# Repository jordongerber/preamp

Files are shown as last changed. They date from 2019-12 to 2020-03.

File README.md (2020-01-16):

# Preamp

## Goals

 * Learn Kicad
 * Become familiar with microcontroller programming
  * SPI
  * Shift registers
  * Mux/Demux
  * Controller interrupts
 * Make a bomb preamp
  * See the block diagram in [/preamp-layout/](https://github.com/SlurpyTurts/preamp/tree/master/preamp-layout) for details of the overall design.

## Implementation
* I am planning to use an ESP32 controller as the MCU
* This preamp will implement relay-controlled input and output switching
  * Inputs
    * Some number of single-ended RCA pairs
 	  * 1-2 pairs balanced pairs
    * relays controlled via demux from MCU. Input control via
      * Front panel rotary encoder
      * Front panel capacitive touch sensors
      * IR remote control
      * Because it's an ESP32, I gotta play with network control
 		* Selection remembered when the device is power-cycled
 	* Outputs
 		* 1x single-ended RCA pair
 		* 1x balanced XLR pair
 		* Headphone Amp
 			* Op-amp driven amp will have single-ended output.
 			* Preamp main outputs will be muted when the headphone amp has a device inserted
 			* When headphones are inserted the previous headphone level will be retained
 			* When headphones are unplugged the main output volume will be retained from before insertion
 		* Upon bootup the headphone volume will come in low (previous state not remembered) but not off, TBD
 * Volume control will be implemented via an MDAC controller
 * Selectable gain setting: 0dB or +12dB
 * Power Supply
 	* Separate linear power supplies for analog and digital sections
 		* 5V
 		* +-15V
 * Headphone Amp
 	* Single-ended Op-amp design
 * Tone Controls
 	* Meh. At the moment I don't really care about tone controls on this unit. If I do add them I'd like to have:
 		* Low/high pass loudness controls w/ controllable corner frequency
 		* Parametric upper-midrange control, 2kHz - 5kHz, variable Q, variable gain (-6dB to 0dB)
 		* Parametric lower-midrange control, 200Hz - 500kHz, variable Q, variable gain (-6dB to +2dB)  

## Instructions

* The files in [/preamp-code](https://github.com/SlurpyTurts/preamp/tree/master/preamp-code) can be run in the Arduino IDE. Currently it is configured for an ESP32.
* The schematic & pcb files in [/preamp-layout/preamp-kicad](https://github.com/SlurpyTurts/preamp/tree/master/preamp-layout/preamp-kicad) can be viewed using KiCad. Open the file ```preamp.pro```
* An overview of the schematic layout of this preamp is located at [preamp/preamp-layout/preamp-kicad/preamp.pdf](https://github.com/SlurpyTurts/preamp/blob/master/preamp-layout/preamp-kicad/preamp.pdf)

## References

### Preamp design
 * https://github.com/FutureSharks/preamp-two
 * https://www.muffsy.com/muffsy-relay-input-selector-4.html
 * https://sound-au.com/articles/balanced-io.htm
 * http://www.interfacebus.com/tone-control-3-band-tlo82-opamp-design.html
 * http://www.thatcorp.com/2181-series_Trimmable_Blackmer_IC_Voltage-Controlled_Amplifiers.shtml

### Power Supply design
 * https://www.eleccircuit.com/dual-adjustable-power-supply-circuit-diagram/

### SPI
 * SPI - http://www.circuitbasics.com/basics-of-the-spi-communication-protocol/
 * shift registers for mux - https://www.brainy-bits.com/get-more-inputs-on-your-arduino-by-using-a-shift-register/
 * https://github.com/espressif/arduino-esp32/blob/master/libraries/SPI/examples/SPI_Multiple_Buses/SPI_Multiple_Buses.ino
 * https://github.com/espressif/arduino-esp32/issues/1942
 * https://github.com/MajenkoLibraries/MCP23S17

### Arduino
  * encoder interrupts - http://bristolwatch.com/arduino/arduino2.htm
  * encoder interrupts - https://www.arduino.cc/reference/en/language/functions/external-interrupts/attachinterrupt/
  * flash memory - https://randomnerdtutorials.com/esp32-flash-memory/

### Other
 * Neopixel - https://www.adafruit.com/product/3094

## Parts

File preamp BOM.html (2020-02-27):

TOTAL BOM COST | 295.59
COMPONENT | SCHEMATIC ENTRY | PARTS SOURCING | FOOTPRINT ASSIGNMENT | MECHANICAL / PCB LAYOUT | CODE
CHASSIS | N/A | TODO | N/A | TODO | N/A
CABLES | N/A | TODO | N/A | TODO | N/A
AC PCA | INITIAL | INITIAL | PRELIMINARY | TODO | N/A
5V PWR PCA | INITIAL | INITIAL | PRELIMINARY | TODO | N/A
15V PWR PCA | INITIAL | INITIAL | PRELIMINARY | TODO | N/A
IO PCA | INITIAL | INITIAL | PRELIMINARY | TODO | N/A
IO SELECT PCA | INITIAL | INITIAL | PRELIMINARY | TODO | PRELIMINARY
BALANCED IO PCA | INITIAL | INITIAL | PRELIMINARY | TODO | TODO
GAIN STAGE PCA | INITIAL | PRELIMINARY | PRELIMINARY | TODO | TODO
MCU PCA | PRELIMINARY | PRELIMINARY | PRELIMINARY | TODO | TODO
FRONT PANEL SELECT PCA | INITIAL | PRELIMINARY | PRELIMINARY | TODO | TODO
HEADPHONE CROSSFEED PCA | INITIAL | TODO | TODO | TODO | TODO
HEADPHONE AMP PCA | PRELIMINARY | TODO | TODO | TODO | N/A
FINAL ASSEMBLY HARDWARE | N/A | TODO | N/A | TODO | N/A
KNOB | N/A | PRELIMINARY | N/A | TODO | N/A
PWR SWITCH | INITIAL | TODO | N/A | TODO | N/A
REMOTE | N/A | TODO | N/A | N/A | TODO
PROCESS STEPS
TODO | hasn’t been started yet
PRELIMINARY | In process of being done, not to first working draft status yet
INITIAL | draft, might be correct?
AWAITING REVIEW | inspect for completeness, correctness
CONFIRMED | has been reviewed, seems like it should work with other components.
PROTOTYPE | built, needs to be inspected to show it is working properly
TROUBLESHOOT | fix any issues found in proto
APPROVED | good to go
DONE | done
DESCRIPTION | QTY | UNIT PRICE | LINE PRICE | REF DES | NOTE | SUPPLIER | SUPPLIER PN | LINK
CHASSIS | 1 | - | - | N/A
CABLES | 1 | - | - | N/A
AC PCA | 1 | 9.12 | 9.12 | N/A
5V PWR PCA | 1 | 28.04 | 28.04 | N/A
15V PWR PCA | 1 | 47.12 | 47.12 | N/A
MAIN IO PCA | 1 | 83.86 | 83.86 | N/A
BALANCED IO PCA | 1 | 10.56 | 10.56 | N/A
IO SELECT PCA | 1 | 42.44 | 42.44 | N/A
MCU PCA | 1 | 6.53 | 6.53 | N/A
FRONT PANEL SELECT PCA | 1 | 10.36 | 10.36 | N/A
ENCODER | 2 | 1.50 | 3.00 | N/A |  | AMAZON |  | https://www.amazon.com/WGCD-KY-040-Degree-Encoder-Arduino/dp/B07B68H6R8
GAIN STAGE PCA | 1 | 29.85 | 29.85 | SW1, SW2
HEADPHONE CROSSFEED PCA | 1 | - | -
HEADPHONE AMP PCA | 1 | 0.62 | 0.62
FINAL ASSEMBLY HARDWARE | 1 |  | -
ENCODER KNOB | 2 |  | -
PWR SWITCH | 1 | 17.29 | 17.29 | SW3 |  | DIGIKEY | 1948-2261-ND | https://www.digikey.com/product-detail/en/eao/82-5151.2123/1948-2261-ND/8736349
IEC CONN | 1 | 0.88 | 0.88 |  |  | DIGIKEY | Q336-ND | https://www.digikey.com/product-detail/en/qualtek/703W-00-08/Q336-ND/1164207
REMOTE | 1 |  | - | N/A
CAPACITIVE TOUCH SWITCH MOMENTARY | 8 | 0.74 | 5.92 |  |  | AMAZON | 3-01-0019 | https://www.amazon.com/gp/product/B00HFQEFWQ/ref=ppx_yo_dt_b_asin_title_o02_s04?
DESCRIPTION | QTY | UNIT PRICE | LINE PRICE | REF DES | NOTE | SUPPLIER | SUPPLIER PN | LINK
 |  |  | -
DESCRIPTION | QTY | UNIT PRICE | LINE PRICE | REF DES | NOTE | SUPPLIER | SUPPLIER PN | LINK
 |  |  | -
DESCRIPTION | QTY | UNIT PRICE | LINE PRICE | REF DES | NOTE | SUPPLIER | SUPPLIER PN | LINK
AC PCB | 1 |  | - | N/A
CAP CER 0.1UF 1KV X7R 1812 | 1 | 0.94 | 0.94 | C1 | power switch bypass capacitor | DIGIKEY | 399-9854-1-ND | https://www.digikey.com/product-detail/en/kemet/C1812C104KDRAC7800/399-9854-1-ND/3726199
RES SMD 4.7M OHM 1% 1/4W 1206 | 1 | 0.10 | 0.10 | R1 | bleedoff resistor | DIGIKEY | 311-4.70MFRCT-ND | https://www.digikey.com/product-detail/en/yageo/RC1206FR-074M7L/311-4.70MFRCT-ND/731835
FUSE HLDR CARTRIDGE 250V 5A PCB | 1 | 0.62 | 0.62 | F1 |  | DIGIKEY | 36-4527-ND | https://www.digikey.com/product-detail/en/keystone-electronics/4527/36-4527-ND/8397
FUSE GLASS 500MA 220VAC 5X20MM | 1 | 2.38 | 2.38 | N/A | Installed in F1 | DIGIKEY | 486-1863-ND | https://www.digikey.com/products/en/circuit-protection/fuses/139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
TERM BLK 3P SIDE ENT 5.08MM PCB | 3 | 1.65 | 4.95 | J2 – J4 | Connect to AC from EIC, supply to DC supplies in preamp (120V) | DIGIKEY | 277-1248-ND | https://www.digikey.com/product-detail/en/phoenix-contact/1729131/277-1248-ND/260616
CONN HEADER VERT 2POS 2.5MM | 1 | 0.13 | 0.13 | J1 | Connect power switch to pcb | DIGIKEY | 455-1611-ND | https://www.digikey.com/product-detail/en/jst-sales-america-inc/B2B-EH-A-LF-SN/455-1611-ND/926520
DESCRIPTION | QTY | UNIT PRICE | LINE PRICE | REF DES | NOTE | SUPPLIER | SUPPLIER PN | LINK
+5V PCB | 1 |  | - | N/A
XFRMR LAMINATED 6VA THRU HOLE | 1 | 11.62 | 11.62 | T2 |  | DIGIKEY | HM4309-ND | https://www.digikey.com/product-detail/en/hammond-manufacturing/164F12/HM4309-ND/454308
BRIDGE RECT 1P 200V 1.5A 4DIP | 1 | 0.50 | 0.50 | D8 |  | DIGIKEY | DF02M-ND | https://www.digikey.com/product-detail/en/on-semiconductor/DF02M/DF02M-ND/976938
FUSE HLDR CARTRIDGE 250V 5A PCB | 1 | 0.62 | 0.62 | F3 |  | DIGIKEY | 36-4527-ND | https://www.digikey.com/product-detail/en/keystone-electronics/4527/36-4527-ND/8397
FUSE GLASS 500MA 220VAC 5X20MM | 1 | 2.38 | 2.38 | N/A | Installed in F3 | DIGIKEY | 486-1863-ND | https://www.digikey.com/products/en/circuit-protection/fuses/139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
LED RED CLEAR 1206 SMD | 1 | 0.27 | 0.27 | D9 | Power indicator LED | DIGIKEY | 160-1167-1-ND | https://www.digikey.com/product-detail/en/lite-on-inc/LTST-C150CKT/160-1167-1-ND/269239
RES SMD 430 OHM 1% 1/4W 1206 | 1 | 0.07 | 0.07 | R8 | Current set resistor for power indicator LED | DIGIKEY | 311-430FRCT-ND | https://www.digikey.com/product-detail/en/yageo/RC1206FR-07430RL/311-430FRCT-ND/731861
TERM BLK 3P SIDE ENT 5.08MM PCB | 1 | 1.65 | 1.65 | J9 | Conn to AC board. Ties to 15V supply gnd | DIGIKEY | 277-1248-ND | https://www.digikey.com/product-detail/en/phoenix-contact/1729131/277-1248-ND/260616
CONN HEADER VERT 2POS 2.5MM | 3 | 0.131 | 0.39 | J10 – J12 | 5V OUTPUT | DIGIKEY | 455-1611-ND | https://www.digikey.com/product-detail/en/jst-sales-america-inc/B2B-EH-A-LF-SN/455-1611-ND/926520
IC REG LINEAR 5V 1A TO220-3 | 1 | 1.54 | 1.54 | U1 |  | DIGIKEY | 296-47192-ND | https://www.digikey.com/product-detail/en/texas-instruments/LM7805CT-NOPB/296-47192-ND/3901929
RES 10 OHM 1W 1% AXIAL | 1 | 0.37 | 0.37 | R9 |  | DIGIKEY | RSF1FT10R0CT-ND | https://www.digikey.com/product-detail/en/stackpole-electronics-inc/RSF1FT10R0/RSF1FT10R0CT-ND/6594481
CAP ALUM 2200UF 20% 35V RADIAL | 2 | 3.04 | 6.08 | C12, C13 |  | DIGIKEY | 493-4615-ND | https://www.digikey.com/products/en/capacitors/aluminum-electrolytic-capacitors/58?k=capacitor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
CAP CER 0.1UF 50V X7R 1206 | 2 | 0.26 | 0.52 | C14, C15 |  | DIGIKEY | 311-1435-1-ND | https://www.digikey.com/product-detail/en/yageo/CC1206JRX7R9BB104/311-1435-1-ND/2833741
CAP ALUM 100UF 20% 35V RADIAL | 1 | 0.51 | 0.51 | C16 |  | DIGIKEY | 493-4662-1-ND | https://www.digikey.com/product-detail/en/nichicon/UKA1V101MED1TD/493-4662-1-ND/2787089
RES SMD 240 OHM 1% 1/4W 1206 | 1 | 0.10 | 0.10 | R10 |  | DIGIKEY | 311-240FRCT-ND | https://www.digikey.com/products/en/resistors/chip-resistor-surface-mount/52?k=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
TRIMMER 5K OHM 0.5W PC PIN TOP | 1 | 1.02 | 1.02 | RV3 | Output voltage adjustment | DIGIKEY | 3362P-502LF-ND | https://www.digikey.com/product-detail/en/bourns-inc/3362P-1-502LF/3362P-502LF-ND/1088421
DIODE GEN PURP 50V 1A SOD123FL | 2 | 0.20 | 0.40 | D10, D11 |  | DIGIKEY | SM4001PL-TPMSCT-ND | https://www.digikey.com/product-detail/en/micro-commercial-co/SM4001PL-TP/SM4001PL-TPMSCT-ND/1793403
DESCRIPTION | QTY | UNIT PRICE | LINE PRICE | REF DES | NOTE | SUPPLIER | SUPPLIER PN | LINK
+/-15V PCB | 1 |  | - | N/A
XFRMR LAMINATED 36VA THRU HOLE | 1 | 19.06 | 19.06 | T1 |  | DIGIKEY | HM4343-ND | https://www.digikey.com/product-detail/en/hammond-manufacturing/164J28/HM4343-ND/454433
BRIDGE RECT 1P 200V 1.5A 4DIP | 1 | 0.50 | 0.50 | D1 |  | DIGIKEY | DF02M-ND | https://www.digikey.com/product-detail/en/on-semiconductor/DF02M/DF02M-ND/976938
FUSE HLDR CARTRIDGE 250V 5A PCB | 1 | 0.62 | 0.62 | F2 |  | DIGIKEY | 36-4527-ND | https://www.digikey.com/product-detail/en/keystone-electronics/4527/36-4527-ND/8397
FUSE GLASS 500MA 220VAC 5X20MM | 1 | 2.38 | 2.38 | N/A | Installed in F2 | DIGIKEY | 486-1863-ND | https://www.digikey.com/products/en/circuit-protection/fuses/139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
LED GREEN CLEAR 1206 SMD | 2 | 0.24 | 0.48 | D2, D3 | Power indicator LEDs | DIGIKEY | 160-1169-1-ND | https://www.digikey.com/product-detail/en/lite-on-inc/LTST-C150GKT/160-1169-1-ND/269241
RES SMD 430 OHM 1% 1/4W 1206 | 2 | 0.07 | 0.14 | R2, R3 | Current set resistor for power indicator LEDs | DIGIKEY | 311-430FRCT-ND | https://www.digikey.com/product-detail/en/yageo/RC1206FR-07430RL/311-430FRCT-ND/731861
CONN HEADER VERT 3POS 2.5MM | 3 | 0.48 | 1.44 | J6 – J8 | +-15V OUTPUT | DIGIKEY | 455-1612-ND | https://www.digikey.com/product-detail/en/jst-sales-america-inc/B3B-EH-A-LF-SN/455-1612-ND/926521
IC REG LINEAR 5V 1A TO220-3 | 1 | 1.54 | 1.54 | U1 |  | DIGIKEY | 296-47192-ND | https://www.digikey.com/product-detail/en/texas-instruments/LM7805CT-NOPB/296-47192-ND/3901929
IC REG LINEAR -5V 1.5A TO220-3 | 1 | 1.63 | 1.63 | U2 |  | DIGIKEY | LM7905CTNS/NOPB-ND | https://www.digikey.com/product-detail/en/texas-instruments/LM7905CT-NOPB/LM7905CTNS-NOPB-ND/6349
RES 10 OHM 1W 1% AXIAL | 2 | 0.37 | 0.74 | R4, R5 |  | DIGIKEY | RSF1FT10R0CT-ND | https://www.digikey.com/product-detail/en/stackpole-electronics-inc/RSF1FT10R0/RSF1FT10R0CT-ND/6594481
CAP ALUM 2200UF 20% 35V RADIAL | 4 | 3.04 | 12.16 | C2 – C5 |  | DIGIKEY | 493-4615-ND | https://www.digikey.com/products/en/capacitors/aluminum-electrolytic-capacitors/58?k=capacitor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
DIODE GEN PURP 50V 1A SOD123FL | 4 | 0.20 | 0.80 | D4 – D7 |  | DIGIKEY | SM4001PL-TPMSCT-ND | https://www.digikey.com/product-detail/en/micro-commercial-co/SM4001PL-TP/SM4001PL-TPMSCT-ND/1793403
CAP ALUM 100UF 20% 35V RADIAL | 2 | 0.51 | 1.02 | C10, C11 |  | DIGIKEY | 493-4662-1-ND | https://www.digikey.com/product-detail/en/nichicon/UKA1V101MED1TD/493-4662-1-ND/2787089
CAP CER 0.1UF 100V X7R 0805 | 4 | 0.18 | 0.72 | C6 – C8 |  | DIGIKEY | 311-1435-1-ND | https://www.digikey.com/product-detail/en/yageo/CC1206JRX7R9BB104/311-1435-1-ND/2833741
RES SMD 240 OHM 1% 1/4W 1206 | 2 | 0.10 | 0.20 | R6, R7 |  | DIGIKEY | 311-240FRCT-ND | https://www.digikey.com/products/en/resistors/chip-resistor-surface-mount/52?k=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
TRIMMER 5K OHM 0.5W PC PIN TOP | 2 | 1.02 | 2.04 | RV1, RV2 | Output voltage adjustment | DIGIKEY | 3362P-502LF-ND | https://www.digikey.com/product-detail/en/bourns-inc/3362P-1-502LF/3362P-502LF-ND/1088421
TERM BLK 3P SIDE ENT 5.08MM PCB | 1 | 1.65 | 1.65 | J5 | Conn to AC board. Ties to 5V supply gnd | DIGIKEY | 277-1248-ND | https://www.digikey.com/product-detail/en/phoenix-contact/1729131/277-1248-ND/260616
DESCRIPTION | QTY | UNIT PRICE | LINE PRICE | REF DES | NOTE | SUPPLIER | SUPPLIER PN | LINK
MAIN IO PCB | 1 |  | - | N/A
RCA JACK PC MOUNT WHITE | 7 | 5.99 | 41.93 | J37.1 – J41.1, J49.1, J50.1 | Most likely a knockoff, I don’t care. | GOOD COMPONENT | CMC 805-2.5F-G | https://www.goodcomponent.com/products/connectors-switches/rca-connector/cmc-805-25f-g-gold-plated-brass-female-rca-jack-connector-whitered-cmc-805-25f-g-855.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
RCA JACK PC MOUNT RED | 7 | 5.99 | 41.93 | J37.2 – J41.2, J49.2, J50.2 | Most likely a knockoff, I don’t care. | GOOD COMPONENT | CMC 805-2.5F-G | https://www.goodcomponent.com/products/connectors-switches/rca-connector/cmc-805-25f-g-gold-plated-brass-female-rca-jack-connector-whitered-cmc-805-25f-g-855.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
DESCRIPTION | QTY | UNIT PRICE | LINE PRICE | REF DES | NOTE | SUPPLIER | SUPPLIER PN | LINK
BALANCED IO PCB | 1 |  | - | N/A
XLR FEMALE | 2 | 0.92 | 1.84 |  |  | MOUSER | 568-NC3FAAV-1 | https://www.mouser.com/ProductDetail/Neutrik/NC3FAAV1
XLR MALE | 2 | 0.77 | 1.54 |  |  | MOUSER | 568-NC3MAAV-1 | https://www.mouser.com/ProductDetail/Neutrik/NC3MAAV-1?qs=3hqMSz60ubQNQZ6GY809OQ%3D%3D
LED GREEN CLEAR 1206 SMD | 2 | 0.24 | 0.48 | D14, D15 | Power indicator LEDs | DIGIKEY | 160-1169-1-ND | https://www.digikey.com/product-detail/en/lite-on-inc/LTST-C150GKT/160-1169-1-ND/269241
RES SMD 430 OHM 1% 1/4W 1206 | 2 | 0.07 | 0.14 | R19, R24 | Current set resistor for power indicator LEDs | DIGIKEY | 311-430FRCT-ND | https://www.digikey.com/product-detail/en/yageo/RC1206FR-07430RL/311-430FRCT-ND/731861
IC OPAMP JFET 2 CIRCUIT 8DIP | 3 | 0.607 | 1.82 | U6 – U8 | Any dual op amp that fits TL072 Pinout | DIGIKEY | 296-14997-5-ND | https://www.digikey.com/product-detail/en/texas-instruments/TL072IP/296-14997-5-ND/563039
CONN HEADER VERT 3POS 2.5MM | 2 | 0.48 | 0.96 | J31, J32 | +/-15VDC | DIGIKEY | 455-1612-ND | https://www.digikey.com/product-detail/en/jst-sales-america-inc/B3B-EH-A-LF-SN/455-1612-ND/926521
CONN HEADER VERT 3POS 2.54MM | 1 | 0.14 | 0.14 | J34 |  | DIGIKEY | 952-2264-ND | https://www.digikey.com/product-detail/en/harwin-inc/M20-9990346/952-2264-ND/3728228
CONN RCPT 3POS 0.1 TIN PCB | 1 | 0.64 | 0.64 | J33 |  | DIGIKEY | 952-1784-ND | https://www.digikey.com/product-detail/en/harwin-inc/M20-7820346/952-1784-ND/3727753
RES SMD 1K OHM 1% 1/4W 1206 | 4 | 0.1 | 0.40 | R11 – R14 |  | DIGIKEY | 311-1.00KFRCT-ND | https://www.digikey.com/product-detail/en/yageo/RC1206FR-071KL/311-1.00KFRCT-ND/731334
RES SMD 9.09K OHM 1% 1/4W 1206 | 4 | 0.1 | 0.40 | R15 – R18 |  | DIGIKEY | 311-9.09KFRCT-ND | https://www.digikey.com/products/en/resistors/chip-resistor-surface-mount/52?k=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
RES SMD 10K OHM 1% 1/4W 1206 | 16 | 0.07 | 1.12 | R20 – R23, R27 – R38 |  | DIGIKEY | 311-10.0KFRCT-ND | https://www.digikey.com/product-detail/en/yageo/RC1206FR-0710KL/311-10.0KFRCT-ND/731430
RES SMD 100 OHM 1% 1/4W 1206 | 6 | 0.1 | 0.60 | R25, R26, R39 – R42 |  | DIGIKEY | 311-100FRCT-ND | https://www.digikey.com/product-detail/en/yageo/RC1206FR-07100RL/311-100FRCT-ND/731438
CAP CER 3300PF 100V X7R 0805 | 4 | 0.12 | 0.48 | C17 – C20 |  | DIGIKEY | 311-1471-1-ND | https://www.digikey.com/product-detail/en/yageo/CC0805KRX7R0BB332/311-1471-1-ND/2833777
DESCRIPTION | QTY | UNIT PRICE | LINE PRICE | REF DES | NOTE | SUPPLIER | SUPPLIER PN | LINK
IO SELECT PCB | 1 |  | - | N/A
IC I/O EXPANDER SPI 16B 28SDIP | 1 | 1.26 | 1.26 | U9 |  | DIGIKEY | MCP23S17-E/SP-ND | https://www.digikey.com/product-detail/en/microchip-technology/MCP23S17-E-SP/MCP23S17-E-SP-ND/894276
IC PWR RELAY 7NPN 1:1 16SO | 2 | 0.59 | 1.18 | U10, U11 |  | DIGIKEY | ULN2003ADR2GOSCT-ND | https://www.digikey.com/product-detail/en/on-semiconductor/ULN2003ADR2G/ULN2003ADR2GOSCT-ND/2623488
RELAY TELECOM DPDT 1A 5VDC | 7 | 4.69 | 32.83 | K1 – K7 |  | DIGIKEY | Z2144-ND | https://www.digikey.com/product-detail/en/omron-electronics-inc-emc-div/G6JU-2P-Y-DC5/Z2144-ND/699971
RES SMD 430 OHM 1% 1/4W 1206 | 1 | 0.07 | 0.07 | R43 | Current set resistor for power indicator LED | DIGIKEY | 311-430FRCT-ND | https://www.digikey.com/product-detail/en/yageo/RC1206FR-07430RL/311-430FRCT-ND/731861
LED RED CLEAR 1206 SMD | 1 | 0.27 | 0.27 | D16 | Power indicator LED | DIGIKEY | 160-1167-1-ND | https://www.digikey.com/product-detail/en/lite-on-inc/LTST-C150CKT/160-1167-1-ND/269239
CONN HEADER VERT 2POS 2.5MM | 2 | 0.14 | 0.28 | J61, J62 |  | DIGIKEY | 455-1611-ND | https://www.digikey.com/product-detail/en/jst-sales-america-inc/B2B-EH-A-LF-SN/455-1611-ND/926520
CONN HEADER VERT 3POS 2.54MM | 6 | 0.14 | 0.82 | J52 – J56, J59 |  | DIGIKEY | 952-2264-ND | https://www.digikey.com/product-detail/en/harwin-inc/M20-9990346/952-2264-ND/3728228
CONN RCPT 3POS 0.1 TIN PCB | 4 | 0.64 | 2.55 | J51, J60, J63, J64 |  | DIGIKEY | 952-1784-ND | https://www.digikey.com/product-detail/en/harwin-inc/M20-7820346/952-1784-ND/3727753
CONN RCPT 8POS 0.1 GOLD PCB | 2 | 1.1 | 2.20 | J57, J58 |  | DIGIKEY | 952-1823-ND | https://www.digikey.com/products/en/connectors-interconnects/rectangular-connectors-headers-receptacles-female-sockets/315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
RES SMD 51 OHM 1% 1/4W 1206 | 14 | 0.07 | 0.98 | R44 – R57 |  | DIGIKEY | 311-51.0FRCT-ND | https://www.digikey.com/product-detail/en/yageo/RC1206FR-0751RL/311-51.0FRCT-ND/731920
DESCRIPTION | QTY | UNIT PRICE | LINE PRICE | REF DES | NOTE | SUPPLIER | SUPPLIER PN | LINK
GAIN STAGE PCB | 1 |  | - | N/A
RES SMD 430 OHM 1% 1/4W 1206 | 2 | 0.07 | 0.14 | R82, R83, R86 | Current set resistor for power indicator LEDs | DIGIKEY | 311-430FRCT-ND | https://www.digikey.com/product-detail/en/yageo/RC1206FR-07430RL/311-430FRCT-ND/731861
LED GREEN CLEAR 1206 SMD | 2 | 0.24 | 0.48 | D17, D18 | Power indicator LEDs | DIGIKEY | 160-1169-1-ND | https://www.digikey.com/product-detail/en/lite-on-inc/LTST-C150GKT/160-1169-1-ND/269241
LED RED CLEAR 1206 SMD | 1 | 0.27 | 0.27 | D21 | Power indicator LED | DIGIKEY | 160-1167-1-ND | https://www.digikey.com/product-detail/en/lite-on-inc/LTST-C150CKT/160-1167-1-ND/269239
IC DAC 8BIT V-OUT 14SOIC | 2 | 1.29 | 2.58 | U12, U13 | DAC to set gain | DIGIKEY | MCP4902-E/SL-ND | https://www.digikey.com/product-detail/en/microchip-technology/MCP4902-E-SL/MCP4902-E-SL-ND/2332822
IC OPAMP JFET 2 CIRCUIT 8DIP | 4 | 0.607 | 2.43 | U14, U15, U18, U21 | Any dual op amp that fits TL072 Pinout | DIGIKEY | 296-14997-5-ND | https://www.digikey.com/product-detail/en/texas-instruments/TL072IP/296-14997-5-ND/563039
Audio Amplifiers Trimmable VCA .02% THD | 4 | 5.05 | 20.20 | U16, U17, U19, U20 | Sets gain of preamp, ctrl voltage supplied from MCP4902 | MOUSER | 887-2181CS08-U | https://www.mouser.com/ProductDetail/THAT/2181CS08-U
RES SMD 330 OHM 1% 1/4W 1206 | 1 | 0.07 | 0.07 | R86 | Current set resistor for power indicator LEDs | DIGIKEY | 311-330FRCT-ND | https://www.digikey.com/products/en/resistors/chip-resistor-surface-mount/52?k=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
RES SMD 2K OHM 1% 1/4W 1206 | 4 | 0.1 | 0.40 | R70 – R73 |  | DIGIKEY | 311-2.00KFRCT-ND | https://www.digikey.com/product-detail/en/yageo/RC1206FR-072KL/311-2.00KFRCT-ND/731559
RES SMD 178K OHM 1% 1/4W 1206 | 4 | $0.10 | 0.40 | R62, R64, R66, R68 |  | DIGIKEY | 311-178KFRCT-ND | https://www.digikey.com/product-detail/en/yageo/RC1206FR-07178KL/311-178KFRCT-ND/731537
RES SMD 6.49K OHM 1% 1/4W 1206 | 4 | $0.10 | 0.40 | R63, R65, R67, R69 |  | DIGIKEY | 311-6.49KFRCT-ND | https://www.digikey.com/product-detail/en/yageo/RC1206FR-076K49L/311-6.49KFRCT-ND/731969
RES SMD 6.34K OHM 1% 1/4W 1206 | 4 | $0.10 | 0.40 | R58 – R61 |  | DIGIKEY | 311-6.34KFRCT-ND | https://www.digikey.com/product-detail/en/yageo/RC1206FR-076K34L/311-6.34KFRCT-ND/731966
CAP CER 0.1UF 100V X7R 0805 | 4 | $0.18 | 0.72 | C21 – C24 |  | DIGIKEY | 311-2083-1-ND | https://www.digikey.com/product-detail/en/yageo/CC0805KKX7R0BB104/311-2083-1-ND/5962185
RES SMD 20K OHM 1% 1/4W 1206 | 8 | $0.10 | 0.80 | R74 – R81 |  | DIGIKEY | 311-20.0KFRCT-ND | https://www.digikey.com/product-detail/en/yageo/RC1206FR-0720KL/311-20.0KFRCT-ND/731619
CAP CER 22PF 100V C0G/NPO 0805 | 4 | $0.14 | 0.56 | C31, C32, C35, C36 |  | DIGIKEY | 311-1840-1-ND | https://www.digikey.com/product-detail/en/yageo/CC0805JRNPO0BN220/311-1840-1-ND/5195742
DESCRIPTION | QTY | UNIT PRICE | LINE PRICE | REF DES | NOTE | SUPPLIER | SUPPLIER PN | LINK
MCU PCB | 1 |  | - | N/A
ESP32 MCU | 1 | 6.53 | 6.53 |  |  | AMAZON |  | https://www.amazon.com/gp/product/B07Q576VWZ/ref=ppx_yo_dt_b_asin_title_o02_s01?ie=UTF8&psc=1
DESCRIPTION | QTY | UNIT PRICE | LINE PRICE | REF DES | NOTE | SUPPLIER | SUPPLIER PN | LINK
FRONT PANEL PCB | 1 |  | - | N/A
MULTIPLE SWITCH DETECTION INTERFACE | 1 | 4.19 | 4.19 |  | condenses up to 22 input switches to SPI and flag line | DIGIKEY | MC33978AEK-ND | https://www.digikey.com/product-detail/en/nxp-usa-inc/MC33978AEK/MC33978AEK-ND/5451804
CONN HEADER VERT 3POS 2.5MM | 8 | 0.48 | 3.84 | J72 – J79 |  | DIGIKEY | 455-1612-ND | https://www.digikey.com/product-detail/en/jst-sales-america-inc/B3B-EH-A-LF-SN/455-1612-ND/926521
RES SMD 100 OHM 1% 1/4W 1206 | 8 | 0.07 | 0.56 | R87 – R94 |  | DIGIKEY | 311-100FRCT-ND | https://www.digikey.com/product-detail/en/yageo/RC1206FR-07100RL/311-100FRCT-ND/731438
CAP CER 0.1UF 100V X7R 1206 | 8 | 0.13 | 1.04 | C37 – C44 |  | DIGIKEY | 311-1488-1-ND | https://www.digikey.com/product-detail/en/yageo/CC1206KKX7R0BB104/311-1488-1-ND/2833794
LED RED CLEAR 1206 SMD | 1 | 0.27 | 0.27 | D9 | Power indicator LED | DIGIKEY | 160-1167-1-ND | https://www.digikey.com/product-detail/en/lite-on-inc/LTST-C150CKT/160-1167-1-ND/269239
RES SMD 330 OHM 1% 1/4W 1206 | 1 | 0.07 | 0.07 | R8 | Current set resistor for power indicator LEDs | DIGIKEY | 311-330FRCT-ND | https://www.digikey.com/products/en/resistors/chip-resistor-surface-mount/52?k=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
CONN HEADER VERT 2POS 2.5MM | 3 | 0.13 | 0.39 | J10 – J12 | 5V OUTPUT | DIGIKEY | 455-1611-ND | https://www.digikey.com/product-detail/en/jst-sales-america-inc/B2B-EH-A-LF-SN/455-1611-ND/926520
DESCRIPTION | QTY | UNIT PRICE | LINE PRICE | REF DES | NOTE | SUPPLIER | SUPPLIER PN | LINK
HEADPHONE CROSSFEED PCB | 1 |  | - | N/A
DESCRIPTION | QTY | UNIT PRICE | LINE PRICE | REF DES | NOTE | SUPPLIER | SUPPLIER PN | LINK
HEADPHONE AMP PCB | 1 |  | - | N/A
LED GREEN CLEAR 1206 SMD | 2 | 0.24 | 0.48 | D19, D20 | Power indicator LEDs | DIGIKEY | 160-1169-1-ND | https://www.digikey.com/product-detail/en/lite-on-inc/LTST-C150GKT/160-1169-1-ND/269241
RES SMD 430 OHM 1% 1/4W 1206 | 2 | 0.07 | 0.14 | R84, R85 | Current set resistor for power indicator LEDs | DIGIKEY | 311-430FRCT-ND | https://www.digikey.com/product-detail/en/yageo/RC1206FR-07430RL/311-430FRCT-ND/731861
DESCRIPTION | QTY | UNIT PRICE | LINE PRICE | REF DES | NOTE | SUPPLIER | SUPPLIER PN | LINK
ENCODER PCB | 1 |  | - | N/A
ROTARY ENCODER | 2 | 1.50 | 3.00 |  |  | AMAZON |  | https://www.amazon.com/WGCD-KY-040-Degree-Encoder-Arduino/dp/B07B68H6R8
https://www.aliexpress.com/item/32826735571.html?scm_id=1007.13338.146400.0&scm-url=1007.13338.146400.0
https://www.aliexpress.com/item/32800269274.html?scm_id=1007.13338.146400.0&scm-url=1007.13338.146400.0
https://www.aliexpress.com/item/32953404871.html?scm_id=1007.13338.146400.0&scm-url=1007.13338.146400.0
https://www.aliexpress.com/item/32627105289.html?scm_id=1007.13338.146400.0&scm-url=1007.13338.146400.0

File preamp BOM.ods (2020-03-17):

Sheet: OVERVIEW
TOTAL BOM COST | $316.82
COMPONENT | SCHEMATIC ENTRY | PARTS SOURCING | FOOTPRINT ASSIGNMENT | MECHANICAL / PCB LAYOUT | CODE
CHASSIS | N/A | TODO | N/A | TODO | N/A
CABLES | N/A | TODO | N/A | TODO | N/A
AC PCA | INITIAL | INITIAL | PRELIMINARY | TODO | N/A
5V PWR PCA | INITIAL | INITIAL | PRELIMINARY | TODO | N/A
15V PWR PCA | INITIAL | INITIAL | PRELIMINARY | TODO | N/A
IO PCA | INITIAL | INITIAL | PRELIMINARY | TODO | N/A
IO SELECT PCA | INITIAL | INITIAL | PRELIMINARY | TODO | PRELIMINARY
BALANCED IO PCA | INITIAL | INITIAL | PRELIMINARY | TODO | TODO
GAIN STAGE PCA | INITIAL | INITIAL | PRELIMINARY | TODO | TODO
MCU PCA | PRELIMINARY | PRELIMINARY | PRELIMINARY | TODO | TODO
FRONT PANEL SELECT PCA | INITIAL | PRELIMINARY | PRELIMINARY | TODO | TODO
HEADPHONE CROSSFEED PCA | INITIAL | TODO | TODO | TODO | TODO
HEADPHONE AMP PCA | INITIAL | TODO | TODO | TODO | N/A
FINAL ASSEMBLY HARDWARE | N/A | TODO | N/A | TODO | N/A
KNOB | N/A | PRELIMINARY | N/A | TODO | N/A
PWR SWITCH | INITIAL | TODO | N/A | TODO | N/A
REMOTE | N/A | TODO | N/A | N/A | TODO
PROCESS STEPS
TODO | hasn’t been started yet
PRELIMINARY | In process of being done, not to first working draft status yet
INITIAL | draft, might be correct?
AWAITING REVIEW | inspect for completeness, correctness
CONFIRMED | has been reviewed, seems like it should work with other components.
PROTOTYPE | built, needs to be inspected to show it is working properly
TROUBLESHOOT | fix any issues found in proto
APPROVED | good to go
DONE | done

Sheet: MAIN ASSEMBLY
DESCRIPTION | QTY | UNIT PRICE | LINE PRICE | REF DES | NOTE | SUPPLIER | SUPPLIER PN | LINK
CHASSIS | 1 | $0.00 | $0.00 | N/A
CABLES | 1 | $0.00 | $0.00 | N/A
AC PCA | 1 | $13.62 | $13.62 | N/A
5V PWR PCA | 1 | $28.04 | $28.04 | N/A
15V PWR PCA | 1 | $47.06 | $47.06 | N/A
MAIN IO PCA | 1 | $83.86 | $83.86 | N/A
BALANCED IO PCA | 1 | $12.64 | $12.64 | N/A
IO SELECT PCA | 1 | $41.49 | $41.49 | N/A
MCU PCA | 1 | $6.53 | $6.53 | N/A
FRONT PANEL SELECT PCA | 1 | $10.67 | $10.67 | N/A
ENCODER | 2 | $1.50 | $3.00 | N/A |  | AMAZON |  | https://www.amazon.com/WGCD-KY-040-Degree-Encoder-Arduino/dp/B07B68H6R8
GAIN STAGE PCA | 1 | $36.25 | $36.25 | SW1, SW2
HEADPHONE CROSSFEED PCA | 1 | $2.24 | $2.24
HEADPHONE AMP PCA | 1 | $7.33 | $7.33
FINAL ASSEMBLY HARDWARE | 1 |  | $0.00
ENCODER KNOB | 2 |  | $0.00
PWR SWITCH | 1 | $17.29 | $17.29 | SW3 |  | DIGIKEY | 1948-2261-ND | https://www.digikey.com/product-detail/en/eao/82-5151.2123/1948-2261-ND/8736349
IEC CONN | 1 | $0.88 | $0.88 |  |  | DIGIKEY | Q336-ND | https://www.digikey.com/product-detail/en/qualtek/703W-00-08/Q336-ND/1164207
REMOTE | 1 |  | $0.00 | N/A
CAPACITIVE TOUCH SWITCH MOMENTARY | 8 | $0.74 | $5.92 |  |  | AMAZON | 3-01-0019 | https://www.amazon.com/gp/product/B00HFQEFWQ/ref=ppx_yo_dt_b_asin_title_o02_s04?

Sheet: CHASSIS
DESCRIPTION | QTY | UNIT PRICE | LINE PRICE | REF DES | NOTE | SUPPLIER | SUPPLIER PN | LINK
 |  |  | $-

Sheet: CABLES
DESCRIPTION | QTY | UNIT PRICE | LINE PRICE | REF DES | NOTE | SUPPLIER | SUPPLIER PN | LINK
 |  |  | $-

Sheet: AC PCA
DESCRIPTION | QTY | UNIT PRICE | LINE PRICE | REF DES | NOTE | SUPPLIER | SUPPLIER PN | LINK
AC PCB | 1 |  | $0.00 | N/A
CAP CER 0.1UF 1KV X7R 1812 | 1 | $0.94 | $0.94 | C1 | power switch bypass capacitor | DIGIKEY | 399-9854-1-ND | https://www.digikey.com/product-detail/en/kemet/C1812C104KDRAC7800/399-9854-1-ND/3726199
RES SMD 4.7M OHM 1% 1/4W 1206 | 1 | $0.10 | $0.10 | R1 | bleedoff resistor | DIGIKEY | 311-4.70MFRCT-ND | https://www.digikey.com/product-detail/en/yageo/RC1206FR-074M7L/311-4.70MFRCT-ND/731835
FUSE HLDR CARTRIDGE 250V 5A PCB | 1 | $0.62 | $0.62 | F1 |  | DIGIKEY | 36-4527-ND | https://www.digikey.com/product-detail/en/keystone-electronics/4527/36-4527-ND/8397
FUSE GLASS 500MA 220VAC 5X20MM | 1 | $2.38 | $2.38 | N/A | Installed in F1 | DIGIKEY | 486-1863-ND | https://www.digikey.com/products/en/circuit-protection/fuses/139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
TERM BLK 3P SIDE ENT 5.08MM PCB | 3 | $1.65 | $4.95 | J2, J5, J7 | Connect to AC from EIC, supply to DC supplies in preamp (120V) | DIGIKEY | 277-1248-ND | https://www.digikey.com/product-detail/en/phoenix-contact/1729131/277-1248-ND/260616
CONN HEADER VERT 2POS 2.5MM | 1 | $0.13 | $0.13 | J3 | Connect power switch to pcb | DIGIKEY | 455-1611-ND | https://www.digikey.com/product-detail/en/jst-sales-america-inc/B2B-EH-A-LF-SN/455-1611-ND/926520
RELAY GEN PURPOSE SPST 16A 5V | 1 | $3.60 | $3.60 | K1 | +/-15V control relay | DIGIKEY | Z5412-ND | https://www.digikey.com/product-detail/en/omron-electronics-inc-emc-div/G5RLU-1A-E-DC5/Z5412-ND/4947140
CONN HDR 2POS 0.1 GOLD PCB | 1 | $0.33 | $0.33 | J6 | relay control from MCU | DIGIKEY | S7035-ND | https://www.digikey.com/product-detail/en/sullins-connector-solutions/PPPC021LFBN-RC/S7035-ND/810174
JUMPER SKT CLOSED TOP BLACK | 1 | $0.35 | $0.35 | N/A | relay bypass jumper | DIGIKEY | 952-2573-ND | https://www.digikey.com/product-detail/en/harwin-inc/M7767-05/952-2573-ND/3922868
CONN HEADER VERT 2POS 2.54MM | 1 | $0.22 | $0.22 | J4 | relay bypass | DIGIKEY | S1011E-02-ND | https://www.digikey.com/product-detail/en/sullins-connector-solutions/PBC02SAAN/S1011E-02-ND/859623

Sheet: 5V PWR PCA
DESCRIPTION | QTY | UNIT PRICE | LINE PRICE | REF DES | NOTE | SUPPLIER | SUPPLIER PN | LINK
+5V PCB | 1 |  | $0.00 | N/A
XFRMR LAMINATED 6VA THRU HOLE | 1 | $11.62 | $11.62 | T2 |  | DIGIKEY | HM4309-ND | https://www.digikey.com/product-detail/en/hammond-manufacturing/164F12/HM4309-ND/454308
BRIDGE RECT 1P 200V 1.5A 4DIP | 1 | $0.50 | $0.50 | D10 |  | DIGIKEY | DF02M-ND | https://www.digikey.com/product-detail/en/on-semiconductor/DF02M/DF02M-ND/976938
FUSE HLDR CARTRIDGE 250V 5A PCB | 1 | $0.62 | $0.62 | F3 |  | DIGIKEY | 36-4527-ND | https://www.digikey.com/product-detail/en/keystone-electronics/4527/36-4527-ND/8397
FUSE GLASS 500MA 220VAC 5X20MM | 1 | $2.38 | $2.38 | N/A | Installed in F3 | DIGIKEY | 486-1863-ND | https://www.digikey.com/products/en/circuit-protection/fuses/139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
LED RED CLEAR 1206 SMD | 1 | $0.27 | $0.27 | D8 | Power indicator LED | DIGIKEY | 160-1167-1-ND | https://www.digikey.com/product-detail/en/lite-on-inc/LTST-C150CKT/160-1167-1-ND/269239
RES SMD 330 OHM 1% 1/4W 1206 | 1 | $0.07 | $0.07 | R8 | Current set resistor for power indicator LED D8 | DIGIKEY | 311-330FRCT-ND | https://www.digikey.com/product-detail/en/yageo/RC1206FR-07330RL/311-330FRCT-ND/731769
TERM BLK 3P SIDE ENT 5.08MM PCB | 1 | $1.65 | $1.65 | J15 | Conn to AC board. Ties to 15V supply gnd | DIGIKEY | 277-1248-ND | https://www.digikey.com/product-detail/en/phoenix-contact/1729131/277-1248-ND/260616
CONN HEADER VERT 2POS 2.5MM | 3 | $0.13 | $0.39 | J12 – J14 | +5V | DIGIKEY | 455-1611-ND | https://www.digikey.com/product-detail/en/jst-sales-america-inc/B2B-EH-A-LF-SN/455-1611-ND/926520
IC REG LINEAR 5V 1A TO220-3 | 1 | $1.54 | $1.54 | U3 |  | DIGIKEY | 296-47192-ND | https://www.digikey.com/product-detail/en/texas-instruments/LM7805CT-NOPB/296-47192-ND/3901929
RES 10 OHM 1W 1% AXIAL | 1 | $0.37 | $0.37 | R9 |  | DIGIKEY | RSF1FT10R0CT-ND | https://www.digikey.com/product-detail/en/stackpole-electronics-inc/RSF1FT10R0/RSF1FT10R0CT-ND/6594481
CAP ALUM 2200UF 20% 35V RADIAL | 2 | $3.04 | $6.08 | C12, C13 |  | DIGIKEY | 493-4615-ND | https://www.digikey.com/products/en/capacitors/aluminum-electrolytic-capacitors/58?k=capacitor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
CAP CER 0.1UF 100V X7R 0805 | 2 | $0.26 | $0.52 | C14, C15 |  | DIGIKEY | 311-1435-1-ND | https://www.digikey.com/product-detail/en/yageo/CC1206JRX7R9BB104/311-1435-1-ND/2833741
CAP ALUM 100UF 20% 35V RADIAL | 1 | $0.51 | $0.51 | C16 |  | DIGIKEY | 493-4662-1-ND | https://www.digikey.com/product-detail/en/nichicon/UKA1V101MED1TD/493-4662-1-ND/2787089
RES SMD 240 OHM 1% 1/4W 1206 | 1 | $0.10 | $0.10 | R10 |  | DIGIKEY | 311-240FRCT-ND | https://www.digikey.com/products/en/resistors/chip-resistor-surface-mount/52?k=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
TRIMMER 5K OHM 0.5W PC PIN TOP | 1 | $1.02 | $1.02 | RV3 | Output voltage adjustment | DIGIKEY | 3362P-502LF-ND | https://www.digikey.com/product-detail/en/bourns-inc/3362P-1-502LF/3362P-502LF-ND/1088421
DIODE GEN PURP 50V 1A SOD123FL | 2 | $0.20 | $0.40 | D9, D11 |  | DIGIKEY | SM4001PL-TPMSCT-ND | https://www.digikey.com/product-detail/en/micro-commercial-co/SM4001PL-TP/SM4001PL-TPMSCT-ND/1793403

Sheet: 15V PWR PCA
DESCRIPTION | QTY | UNIT PRICE | LINE PRICE | REF DES | NOTE | SUPPLIER | SUPPLIER PN | LINK
+/-15V PCB | 1 |  | $0.00 | N/A
XFRMR LAMINATED 36VA THRU HOLE | 1 | $19.06 | $19.06 | T1 |  | DIGIKEY | HM4343-ND | https://www.digikey.com/product-detail/en/hammond-manufacturing/164J28/HM4343-ND/454433
BRIDGE RECT 1P 200V 1.5A 4DIP | 1 | $0.50 | $0.50 | D1 |  | DIGIKEY | DF02M-ND | https://www.digikey.com/product-detail/en/on-semiconductor/DF02M/DF02M-ND/976938
FUSE HLDR CARTRIDGE 250V 5A PCB | 1 | $0.62 | $0.62 | F2 |  | DIGIKEY | 36-4527-ND | https://www.digikey.com/product-detail/en/keystone-electronics/4527/36-4527-ND/8397
FUSE GLASS 500MA 220VAC 5X20MM | 1 | $2.38 | $2.38 | N/A | Installed in F2 | DIGIKEY | 486-1863-ND | https://www.digikey.com/products/en/circuit-protection/fuses/139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
LED GREEN CLEAR 1206 SMD | 2 | $0.24 | $0.48 | D2, D3 | Power indicator LEDs | DIGIKEY | 160-1169-1-ND | https://www.digikey.com/product-detail/en/lite-on-inc/LTST-C150GKT/160-1169-1-ND/269241
RES SMD 1.5K OHM 1% 1/4W 1206 | 2 | $0.07 | $0.14 | R2, R3 | Current set resistor for power indicator LEDs | DIGIKEY | 311-1.50KFRCT-ND | https://www.digikey.com/product-detail/en/yageo/RC1206FR-071K5L/311-1-50KFRCT-ND/731388
CONN HEADER VERT 3POS 2.5MM | 3 | $0.48 | $1.44 | J9 – J11 | +/-15V | DIGIKEY | 455-1612-ND | https://www.digikey.com/product-detail/en/jst-sales-america-inc/B3B-EH-A-LF-SN/455-1612-ND/926521
IC REG LINEAR 15V 1A TO220-3 | 1 | $1.54 | $1.54 | U1 |  | DIGIKEY | 296-44418-5-ND | https://www.digikey.com/product-detail/en/texas-instruments/LM7815CT-NOPB/296-44418-5-ND/3901976
IC REG LINEAR -15V 1.5A TO220-3 | 1 | $1.57 | $1.57 | U2 |  | DIGIKEY | LM7915CT/NOPB-ND | https://www.digikey.com/product-detail/en/texas-instruments/LM7915CT-NOPB/LM7915CT-NOPB-ND/6357
RES 10 OHM 1W 1% AXIAL | 2 | $0.37 | $0.74 | R4, R5 |  | DIGIKEY | RSF1FT10R0CT-ND | https://www.digikey.com/product-detail/en/stackpole-electronics-inc/RSF1FT10R0/RSF1FT10R0CT-ND/6594481
CAP ALUM 2200UF 20% 35V RADIAL | 4 | $3.04 | $12.16 | C2 – C5 |  | DIGIKEY | 493-4615-ND | https://www.digikey.com/products/en/capacitors/aluminum-electrolytic-capacitors/58?k=capacitor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
DIODE GEN PURP 50V 1A SOD123FL | 4 | $0.20 | $0.80 | D4 – D7 |  | DIGIKEY | SM4001PL-TPMSCT-ND | https://www.digikey.com/product-detail/en/micro-commercial-co/SM4001PL-TP/SM4001PL-TPMSCT-ND/1793403
CAP ALUM 100UF 20% 35V RADIAL | 2 | $0.51 | $1.02 | C10, C11 |  | DIGIKEY | 493-4662-1-ND | https://www.digikey.com/product-detail/en/nichicon/UKA1V101MED1TD/493-4662-1-ND/2787089
CAP CER 0.1UF 100V X7R 0805 | 4 | $0.18 | $0.72 | C6 – C9 |  | DIGIKEY | 311-1435-1-ND | https://www.digikey.com/product-detail/en/yageo/CC1206JRX7R9BB104/311-1435-1-ND/2833741
RES SMD 240 OHM 1% 1/4W 1206 | 2 | $0.10 | $0.20 | R6, R7 |  | DIGIKEY | 311-240FRCT-ND | https://www.digikey.com/products/en/resistors/chip-resistor-surface-mount/52?k=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
TRIMMER 5K OHM 0.5W PC PIN TOP | 2 | $1.02 | $2.04 | RV1, RV2 | Output voltage adjustment | DIGIKEY | 3362P-502LF-ND | https://www.digikey.com/product-detail/en/bourns-inc/3362P-1-502LF/3362P-502LF-ND/1088421
TERM BLK 3P SIDE ENT 5.08MM PCB | 1 | $1.65 | $1.65 | J8 | Conn to AC board. Ties to 5V supply gnd | DIGIKEY | 277-1248-ND | https://www.digikey.com/product-detail/en/phoenix-contact/1729131/277-1248-ND/260616

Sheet: MAIN IO PCA
DESCRIPTION | QTY | UNIT PRICE | LINE PRICE | REF DES | NOTE | SUPPLIER | SUPPLIER PN | LINK
MAIN IO PCB | 1 |  | $0.00 | N/A
RCA JACK PC MOUNT WHITE | 7 | $5.99 | $41.93 | J36.1 – J40.1, J48.1, J49.1 | Most likely a knockoff, I don’t care. | GOOD COMPONENT | CMC 805-2.5F-G | https://www.goodcomponent.com/products/connectors-switches/rca-connector/cmc-805-25f-g-gold-plated-brass-female-rca-jack-connector-whitered-cmc-805-25f-g-855.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
RCA JACK PC MOUNT RED | 7 | $5.99 | $41.93 | J36.2 – J40.2, J48.2, J49.2 | Most likely a knockoff, I don’t care. | GOOD COMPONENT | CMC 805-2.5F-G | https://www.goodcomponent.com/products/connectors-switches/rca-connector/cmc-805-25f-g-gold-plated-brass-female-rca-jack-connector-whitered-cmc-805-25f-g-855.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

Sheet: BALANCED IO PCA
DESCRIPTION | QTY | UNIT PRICE | LINE PRICE | REF DES | NOTE | SUPPLIER | SUPPLIER PN | LINK
BALANCED IO PCB | 1 |  | $0.00 | N/A
XLR FEMALE | 2 | $0.92 | $1.84 | J82, J88 |  | MOUSER | 568-NC3FAAV-1 | https://www.mouser.com/ProductDetail/Neutrik/NC3FAAV1
XLR MALE | 2 | $0.77 | $1.54 | J83, J89 |  | MOUSER | 568-NC3MAAV-1 | https://www.mouser.com/ProductDetail/Neutrik/NC3MAAV-1?qs=3hqMSz60ubQNQZ6GY809OQ%3D%3D
LED GREEN CLEAR 1206 SMD | 2 | $0.24 | $0.48 | D59, D60 | Power indicator LEDs | DIGIKEY | 160-1169-1-ND | https://www.digikey.com/product-detail/en/lite-on-inc/LTST-C150GKT/160-1169-1-ND/269241
RES SMD 1.5K OHM 1% 1/4W 1206 | 2 | $0.07 | $0.14 | R100, R105 | Current set resistor for power indicator LEDs | DIGIKEY | 311-1.50KFRCT-ND | https://www.digikey.com/product-detail/en/yageo/RC1206FR-071K5L/311-1-50KFRCT-ND/731388
IC OPAMP GP 2 CIRCUIT 8DMP | 3 | $0.76 | $2.28 | U21 – U23 | Dual op amp standard pinout | DIGIKEY | NJM2068M-ND | https://www.digikey.com/product-detail/en/njr-corporation-njrc/NJM2068M/NJM2068M-ND/805545
CONN HEADER VERT 3POS 2.5MM | 2 | $0.48 | $0.96 | J84, J85 | +/-15VDC | DIGIKEY | 455-1612-ND | https://www.digikey.com/product-detail/en/jst-sales-america-inc/B3B-EH-A-LF-SN/455-1612-ND/926521
CONN HEADER VERT 3POS 2.54MM | 1 | $0.30 | $0.30 | J87 |  | DIGIKEY | S1011E-03-ND | https://www.digikey.com/product-detail/en/sullins-connector-solutions/PBC03SAAN/S1011E-03-ND/859624
CONN HDR 3POS 0.1 GOLD PCB | 1 | $0.37 | $0.37 | J86 |  | DIGIKEY | S7036-ND | https://www.digikey.com/product-detail/en/sullins-connector-solutions/PPPC031LFBN-RC/S7036-ND/810175
RES SMD 909 OHM 1% 1/4W 1206 | 4 | $0.10 | $0.40 | R93, R94, R110, R111 |  | DIGIKEY | 311-909FRCT-ND | https://www.digikey.com/products/en?keywords=%09311-909FRCT-ND
RES SMD 9.09K OHM 1% 1/4W 1206 | 4 | $0.10 | $0.40 | R97, R98, R113, R114 |  | DIGIKEY | 311-9.09KFRCT-ND | https://www.digikey.com/products/en/resistors/chip-resistor-surface-mount/52?k=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
RES SMD 10K OHM 1% 1/4W 1206 | 16 | $0.07 | $1.12 | R90 - R92, R95, R96, R99, R103, R104, R107 – R109, R112, R115, R116, R119, R120 |  | DIGIKEY | 311-10.0KFRCT-ND | https://www.digikey.com/product-detail/en/yageo/RC1206FR-0710KL/311-10.0KFRCT-ND/731430
RES SMD 100 OHM 1% 1/4W 1206 | 6 | $0.10 | $0.60 | R101, R102, R106, R117, R118, R121 |  | DIGIKEY | 311-100FRCT-ND | https://www.digikey.com/product-detail/en/yageo/RC1206FR-07100RL/311-100FRCT-ND/731438
CAP CER 3300PF 100V X7R 0805 | 4 | $0.12 | $0.48 | C49 – C52 |  | DIGIKEY | 311-1471-1-ND | https://www.digikey.com/product-detail/en/yageo/CC0805KRX7R0BB332/311-1471-1-ND/2833777
CAP CER 0.1UF 50V X7R 0805 | 6 | $0.09 | $0.55 | C67 – C72 |  | DIGIKEY | 311-1140-1-ND | https://www.digikey.com/product-detail/en/yageo/CC0805KRX7R9BB104/311-1140-1-ND/303050
RES SMD 100K OHM 1% 1/4W 1206 | 2 | $0.10 | $0.20 | R68, R69 | output high pass filter | DIGIKEY | 311-100KFRCT-ND | https://www.digikey.com/products/en?keywords=311-100KFRCT-ND
SMD/SMT 22UF 25V 20% 0805 | 2 | $0.49 | $0.98 | C73, C74 | output high pass filter | MOUSER | 81-GRM21BR61E226ME4K | https://www.mouser.com/ProductDetail/Murata-Electronics/GRM21BR61E226ME44K

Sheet: IO SELECT PCA
DESCRIPTION | QTY | UNIT PRICE | LINE PRICE | REF DES | NOTE | SUPPLIER | SUPPLIER PN | LINK
IO SELECT PCB | 1 |  | $0.00 | N/A
IC I/O EXPANDER SPI 16B 28SOIC | 1 | $1.26 | $1.26 | U6 |  | DIGIKEY | MCP23S17-E/SO-ND | https://www.digikey.com/product-detail/en/microchip-technology/MCP23S17-E-SO/MCP23S17-E-SO-ND/894275
IC PWR RELAY 7NPN 1:1 16SO | 2 | $0.59 | $1.18 | U7, U8 |  | DIGIKEY | ULN2003ADR2GOSCT-ND | https://www.digikey.com/product-detail/en/on-semiconductor/ULN2003ADR2G/ULN2003ADR2GOSCT-ND/2623488
RELAY TELECOM DPDT 1A 5VDC | 7 | $4.69 | $32.83 | K2 – K8 |  | DIGIKEY | Z2144-ND | https://www.digikey.com/product-detail/en/omron-electronics-inc-emc-div/G6JU-2P-Y-DC5/Z2144-ND/699971
RES SMD 330 OHM 1% 1/4W 1206 | 1 | $0.07 | $0.07 | R20 | Current set resistor for power indicator LED | DIGIKEY | 311-330FRCT-ND | https://www.digikey.com/product-detail/en/yageo/RC1206FR-07330RL/311-330FRCT-ND/731769
LED RED CLEAR 1206 SMD | 1 | $0.27 | $0.27 | D13 | Power indicator LED | DIGIKEY | 160-1167-1-ND | https://www.digikey.com/product-detail/en/lite-on-inc/LTST-C150CKT/160-1167-1-ND/269239
CONN HEADER VERT 2POS 2.5MM | 2 | $0.14 | $0.28 | J60, J61 | +5V | DIGIKEY | 455-1611-ND | https://www.digikey.com/product-detail/en/jst-sales-america-inc/B2B-EH-A-LF-SN/455-1611-ND/926520
CONN HEADER VERT 3POS 2.54MM | 6 | $0.30 | $1.80 | J51 – J54, J57, J58 |  | DIGIKEY | S1011E-03-ND | https://www.digikey.com/product-detail/en/sullins-connector-solutions/PBC03SAAN/S1011E-03-ND/859624
CONN HDR 3POS 0.1 GOLD PCB | 4 | $0.37 | $1.48 | J50, J59, J62, J63 |  | DIGIKEY | S7036-ND | https://www.digikey.com/product-detail/en/sullins-connector-solutions/PPPC031LFBN-RC/S7036-ND/810175
CONN HDR 8POS 0.1 GOLD PCB | 2 | $0.67 | $1.34 | J55, J56 | RELAY CONTROL (OPTIONAL) | DIGIKEY | S7041-ND | https://www.digikey.com/product-detail/en/sullins-connector-solutions/PPPC081LFBN-RC/S7041-ND/810180
RES SMD 51 OHM 1% 1/4W 1206 | 14 | $0.07 | $0.98 | R21 – R34 |  | DIGIKEY | 311-51.0FRCT-ND | https://www.digikey.com/product-detail/en/yageo/RC1206FR-0751RL/311-51.0FRCT-ND/731920

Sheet: GAIN STAGE PCA
DESCRIPTION | QTY | UNIT PRICE | LINE PRICE | REF DES | NOTE | SUPPLIER | SUPPLIER PN | LINK
GAIN STAGE PCB | 1 |  | $0.00 | N/A
RES SMD 330 OHM 1% 1/4W 1206 | 1 | $0.07 | $0.07 | R61 | Current set resistor for power indicator LED | DIGIKEY | 311-330FRCT-ND | https://www.digikey.com/product-detail/en/yageo/RC1206FR-07330RL/311-330FRCT-ND/731769
RES SMD 1.5K OHM 1% 1/4W 1206 | 2 | $0.07 | $0.14 | R59, R60 | Current set resistor for power indicator LEDs | DIGIKEY | 311-1.50KFRCT-ND | https://www.digikey.com/product-detail/en/yageo/RC1206FR-071K5L/311-1-50KFRCT-ND/731388
LED GREEN CLEAR 1206 SMD | 2 | $0.24 | $0.48 | D54, D55 | Power indicator LEDs | DIGIKEY | 160-1169-1-ND | https://www.digikey.com/product-detail/en/lite-on-inc/LTST-C150GKT/160-1169-1-ND/269241
LED RED CLEAR 1206 SMD | 1 | $0.27 | $0.27 | D56 | Power indicator LED | DIGIKEY | 160-1167-1-ND | https://www.digikey.com/product-detail/en/lite-on-inc/LTST-C150CKT/160-1167-1-ND/269239
IC DAC 8BIT V-OUT 14SOIC | 2 | $1.29 | $2.58 | U9, U10 | DAC to set gain | DIGIKEY | MCP4902-E/SL-ND | https://www.digikey.com/product-detail/en/microchip-technology/MCP4902-E-SL/MCP4902-E-SL-ND/2332822
IC OPAMP GP 2 CIRCUIT 8DMP | 2 | $0.76 | $1.52 | U15, U18 | Dual op amp standard pinout | DIGIKEY | NJM2068M-ND | https://www.digikey.com/product-detail/en/njr-corporation-njrc/NJM2068M/NJM2068M-ND/805545
Audio Amplifiers Trimmable VCA .02% THD | 4 | $5.05 | $20.20 | U13, U14, U16, U17 | Sets gain of preamp, ctrl voltage supplied from MCP4902 | MOUSER | 887-2181CS08-U | https://www.mouser.com/ProductDetail/THAT/2181CS08-U
RES SMD 2K OHM 1% 1/4W 1206 | 4 | $0.10 | $0.40 | R47 – R50 |  | DIGIKEY | 311-2.00KFRCT-ND | https://www.digikey.com/product-detail/en/yageo/RC1206FR-072KL/311-2.00KFRCT-ND/731559
RES SMD 178K OHM 1% 1/4W 1206 | 4 | $0.10 | $0.40 | R39, R41, R43, R45 |  | DIGIKEY | 311-178KFRCT-ND | https://www.digikey.com/product-detail/en/yageo/RC1206FR-07178KL/311-178KFRCT-ND/731537
RES SMD 6.49K OHM 1% 1/4W 1206 | 4 | $0.10 | $0.40 | R40, R42, R44, R46 |  | DIGIKEY | 311-6.49KFRCT-ND | https://www.digikey.com/product-detail/en/yageo/RC1206FR-076K49L/311-6.49KFRCT-ND/731969
RES SMD 6.34K OHM 1% 1/4W 1206 | 4 | $0.10 | $0.40 | R35 – R38 |  | DIGIKEY | 311-6.34KFRCT-ND | https://www.digikey.com/product-detail/en/yageo/RC1206FR-076K34L/311-6.34KFRCT-ND/731966
CAP CER 0.1UF 100V X7R 0805 | 4 | $0.18 | $0.72 | C29 – C32 |  | DIGIKEY | 311-2083-1-ND | https://www.digikey.com/product-detail/en/yageo/CC0805KKX7R0BB104/311-2083-1-ND/5962185
RES SMD 20K OHM 1% 1/4W 1206 | 8 | $0.10 | $0.80 | R51 – R58 |  | DIGIKEY | 311-20.0KFRCT-ND | https://www.digikey.com/product-detail/en/yageo/RC1206FR-0720KL/311-20.0KFRCT-ND/731619
CAP CER 22PF 100V C0G/NPO 0805 | 4 | $0.14 | $0.56 | C35, C36, C39, C40 |  | DIGIKEY | 311-1840-1-ND | https://www.digikey.com/product-detail/en/yageo/CC0805JRNPO0BN220/311-1840-1-ND/5195742
CONN HEADER VERT 3POS 2.54MM | 1 | $0.30 | $0.30 | J69 | INPUT | DIGIKEY | S1011E-03-ND | https://www.digikey.com/product-detail/en/sullins-connector-solutions/PBC03SAAN/S1011E-03-ND/859624
CONN HDR 3POS 0.1 GOLD PCB | 2 | $0.37 | $0.74 | J67, J68 | OUTPUT | DIGIKEY | S7036-ND | https://www.digikey.com/product-detail/en/sullins-connector-solutions/PPPC031LFBN-RC/S7036-ND/810175
CONN HEADER VERT 5POS 2.54MM | 1 | $0.44 | $0.44 | J64 | MCU CONN | DIGIKEY | S1011E-05-ND | https://www.digikey.com/product-detail/en/sullins-connector-solutions/PBC05SAAN/S1011E-05-ND/859626
CAP ALUM 2.2UF 20% 35V SMD | 4 | $0.36 | $1.44 | C25 – C28 |  | DIGIKEY | PCE4027CT-ND | https://www.digikey.com/product-detail/en/panasonic-electronic-components/EEE-FC1V2R2R/PCE4027CT-ND/817489
CAP ALUM 47UF 20% 35V SMD | 4 | $0.41 | $1.64 | C33, C34, C37, C38 |  | DIGIKEY | PCE3961CT-ND | https://www.digikey.com/product-detail/en/panasonic-electronic-components/EEE-1VA470WP/PCE3961CT-ND/766337
CONN HEADER VERT 2POS 2.5MM | 2 | $0.13 | $0.26 | J65, J66 | +5V | DIGIKEY | 455-1611-ND | https://www.digikey.com/product-detail/en/jst-sales-america-inc/B2B-EH-A-LF-SN/455-1611-ND/926520
CONN HEADER VERT 3POS 2.5MM | 2 | $0.48 | $0.96 | J70, J71 | +/-15V | DIGIKEY | 455-1612-ND | https://www.digikey.com/product-detail/en/jst-sales-america-inc/B3B-EH-A-LF-SN/455-1612-ND/926521
CAP CER 0.1UF 50V X7R 0805 | 8 | $0.09 | $0.74 | C53 – C60 |  | DIGIKEY | 311-1140-1-ND | https://www.digikey.com/product-detail/en/yageo/CC0805KRX7R9BB104/311-1140-1-ND/303050
IC OPAMP JFET 4 CIRCUIT 14SOIC | 1 | $0.39 | $0.39 | U11 | DAC output buffer | DIGIKEY | 296-1283-1-ND | https://www.digikey.com/product-detail/en/texas-instruments/TL074CDR/296-1283-1-ND/404931
RES SMD 5.1K OHM 1% 1/4W 1206 | 4 | $0.10 | $0.40 | R64 – R67 |  | DIGIKEY | 311-5.10KFRCT-ND | https://www.digikey.com/product-detail/en/yageo/RC1206FR-075K1L/311-5-10KFRCT-ND/731894

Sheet: MCU PCA
DESCRIPTION | QTY | UNIT PRICE | LINE PRICE | REF DES | NOTE | SUPPLIER | SUPPLIER PN | LINK
MCU PCB | 1 |  | $0.00 | N/A
ESP32 MCU | 1 | $6.53 | $6.53 | N/A |  | AMAZON |  | https://www.amazon.com/gp/product/B07Q576VWZ/ref=ppx_yo_dt_b_asin_title_o02_s01?ie=UTF8&psc=1

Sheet: FRONT PANEL SELECT PCA
DESCRIPTION | QTY | UNIT PRICE | LINE PRICE | REF DES | NOTE | SUPPLIER | SUPPLIER PN | LINK
FRONT PANEL PCB | 1 |  | $0.00 | N/A
MULTIPLE SWITCH DETECTION INTERFACE | 1 | $4.19 | $4.19 | U4 | condenses up to 22 input switches to SPI and flag line | DIGIKEY | MC33978AEK-ND | https://www.digikey.com/product-detail/en/nxp-usa-inc/MC33978AEK/MC33978AEK-ND/5451804
CONN HEADER VERT 3POS 2.5MM | 8 | $0.48 | $3.84 | J16 – J23 |  | DIGIKEY | 455-1612-ND | https://www.digikey.com/product-detail/en/jst-sales-america-inc/B3B-EH-A-LF-SN/455-1612-ND/926521
RES SMD 100 OHM 1% 1/4W 1206 | 8 | $0.07 | $0.56 | R11 – R18 |  | DIGIKEY | 311-100FRCT-ND | https://www.digikey.com/product-detail/en/yageo/RC1206FR-07100RL/311-100FRCT-ND/731438
CAP CER 0.1UF 100V X7R 1206 | 8 | $0.13 | $1.04 | C17 – C24 |  | DIGIKEY | 311-1488-1-ND | https://www.digikey.com/product-detail/en/yageo/CC1206KKX7R0BB104/311-1488-1-ND/2833794
LED RED CLEAR 1206 SMD | 1 | $0.27 | $0.27 | D12 | Power indicator LED | DIGIKEY | 160-1167-1-ND | https://www.digikey.com/product-detail/en/lite-on-inc/LTST-C150CKT/160-1167-1-ND/269239
RES SMD 330 OHM 1% 1/4W 1206 | 1 | $0.07 | $0.07 | R19 | Current set resistor for power indicator LEDs | DIGIKEY | 311-330FRCT-ND | https://www.digikey.com/product-detail/en/yageo/RC1206FR-07330RL/311-330FRCT-ND/731769
CONN HEADER VERT 2POS 2.5MM | 2 | $0.13 | $0.26 | J25, J26 | +5V | DIGIKEY | 455-1611-ND | https://www.digikey.com/product-detail/en/jst-sales-america-inc/B2B-EH-A-LF-SN/455-1611-ND/926520
CONN HEADER VERT 5POS 2.54MM | 1 | $0.44 | $0.44 | J24 |  | DIGIKEY | S1011E-05-ND | https://www.digikey.com/product-detail/en/sullins-connector-solutions/PBC05SAAN/S1011E-05-ND/859626
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

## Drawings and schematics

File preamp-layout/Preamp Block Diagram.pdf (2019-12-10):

# Digital Control Layout

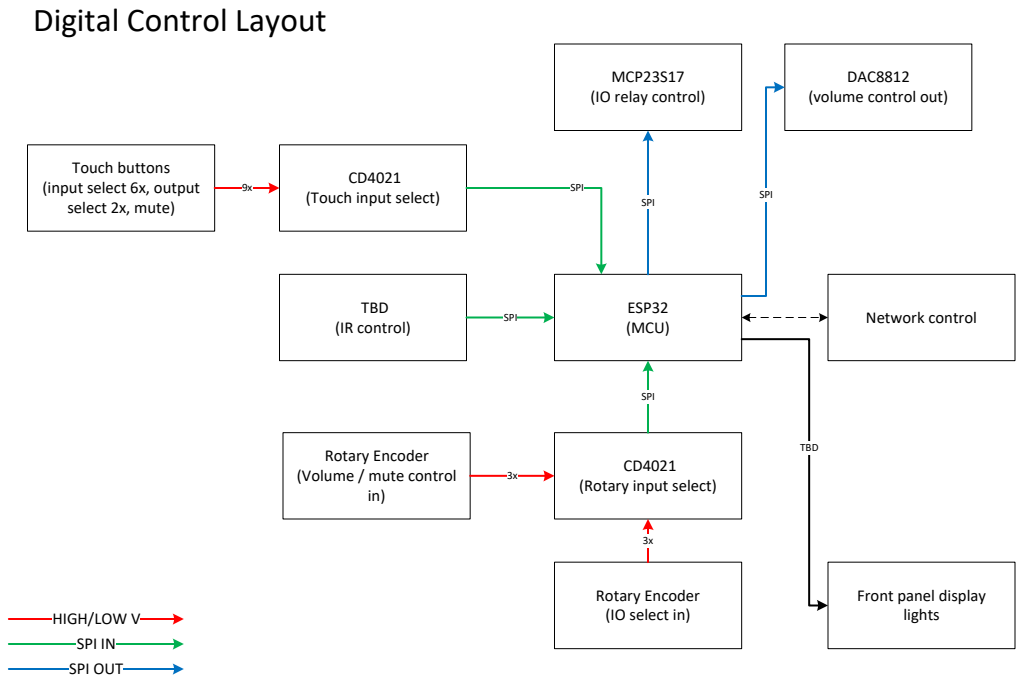
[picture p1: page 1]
ESP32 (MCU); TBD (IR control); Network control; SPI; TBD; HIGH/LOW V SPI IN SPI OUT

MCP23S17
(IO relay control)

DAC8812
(volume control out)

Touch buttons
(input select 6x, output
select 2x, mute)

(Touch input select)

Rotary Encoder
(Volume / mute control

(Rotary input select) ³x

(IO select in)

Front panel display
lights

# Analog Signal Path Layout

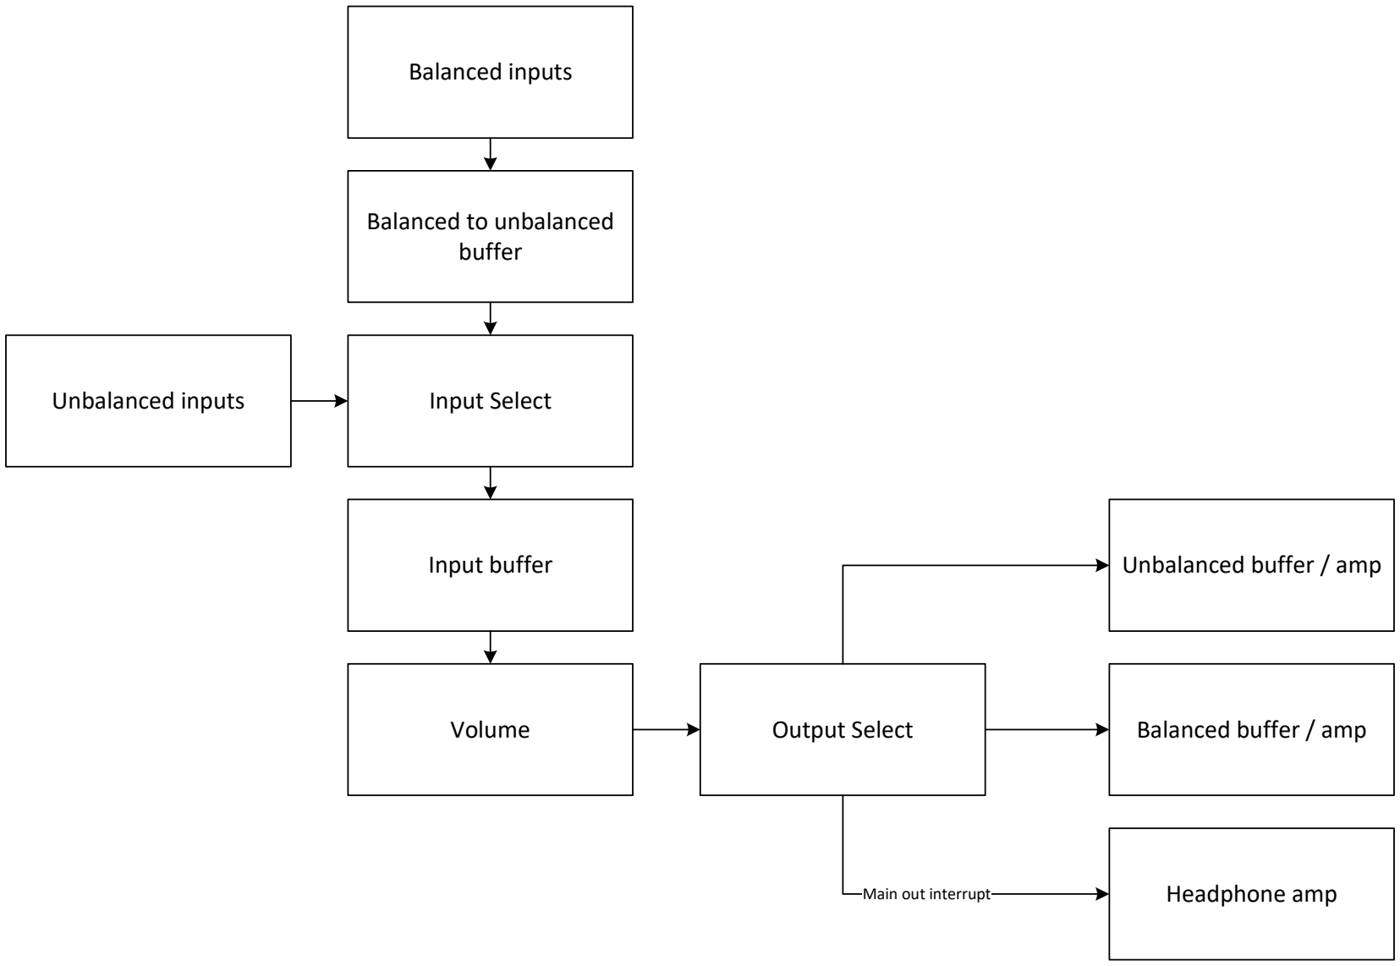
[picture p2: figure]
Input Select; Balanced to unbalanced buffer; Output Select; Unbalanced buffer / amp; Balanced buffer / amp; Headphone amp; Volume; Main out interrupt; Input buffer; Unbalanced inputs; Balanced inputs

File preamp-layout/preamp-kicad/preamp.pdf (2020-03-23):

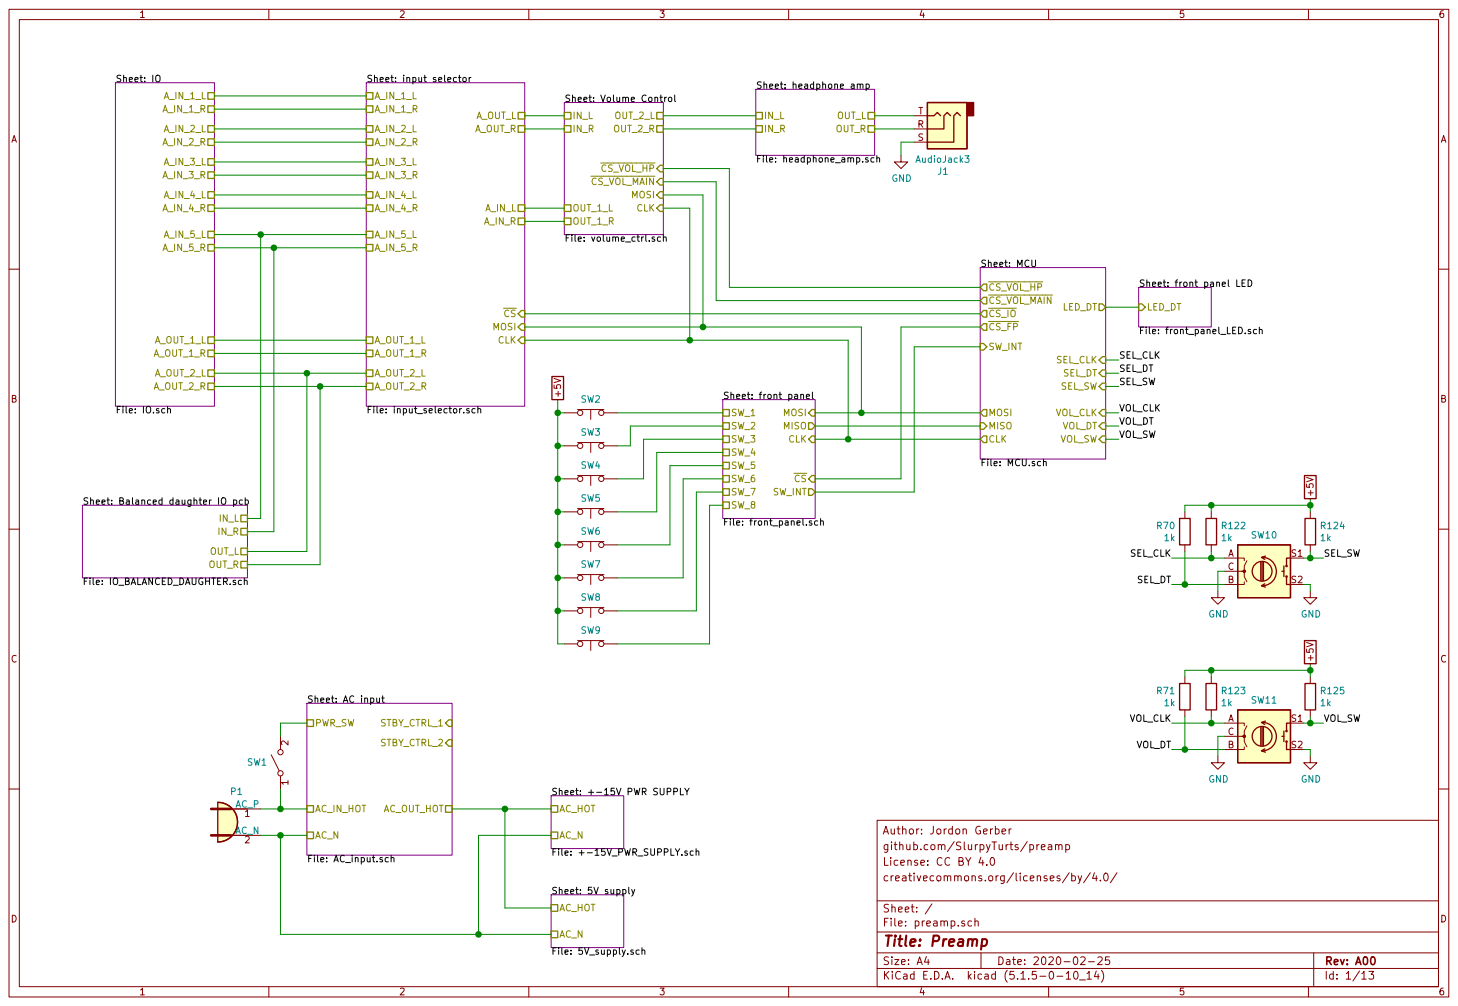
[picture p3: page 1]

Sheet: front panel LED
SEL_DT SEL_SW

A_OUT_2_L Sheet: Balanced daughter IO pcb File: IO_BALANCED_DAUGHTER.sch OUT_R OUT_L

Sheet: front panel
File: front_panel.sch MISO MOSI CLK

File: MCU.sch MISO MOSI CLK

github.com/SlurpyTurts/preamp Author: Jordon Gerber Sheet: AC input

File: preamp.sch Sheet: / creativecommons.org/licenses/by/4.0/ License: CC BY 4.0

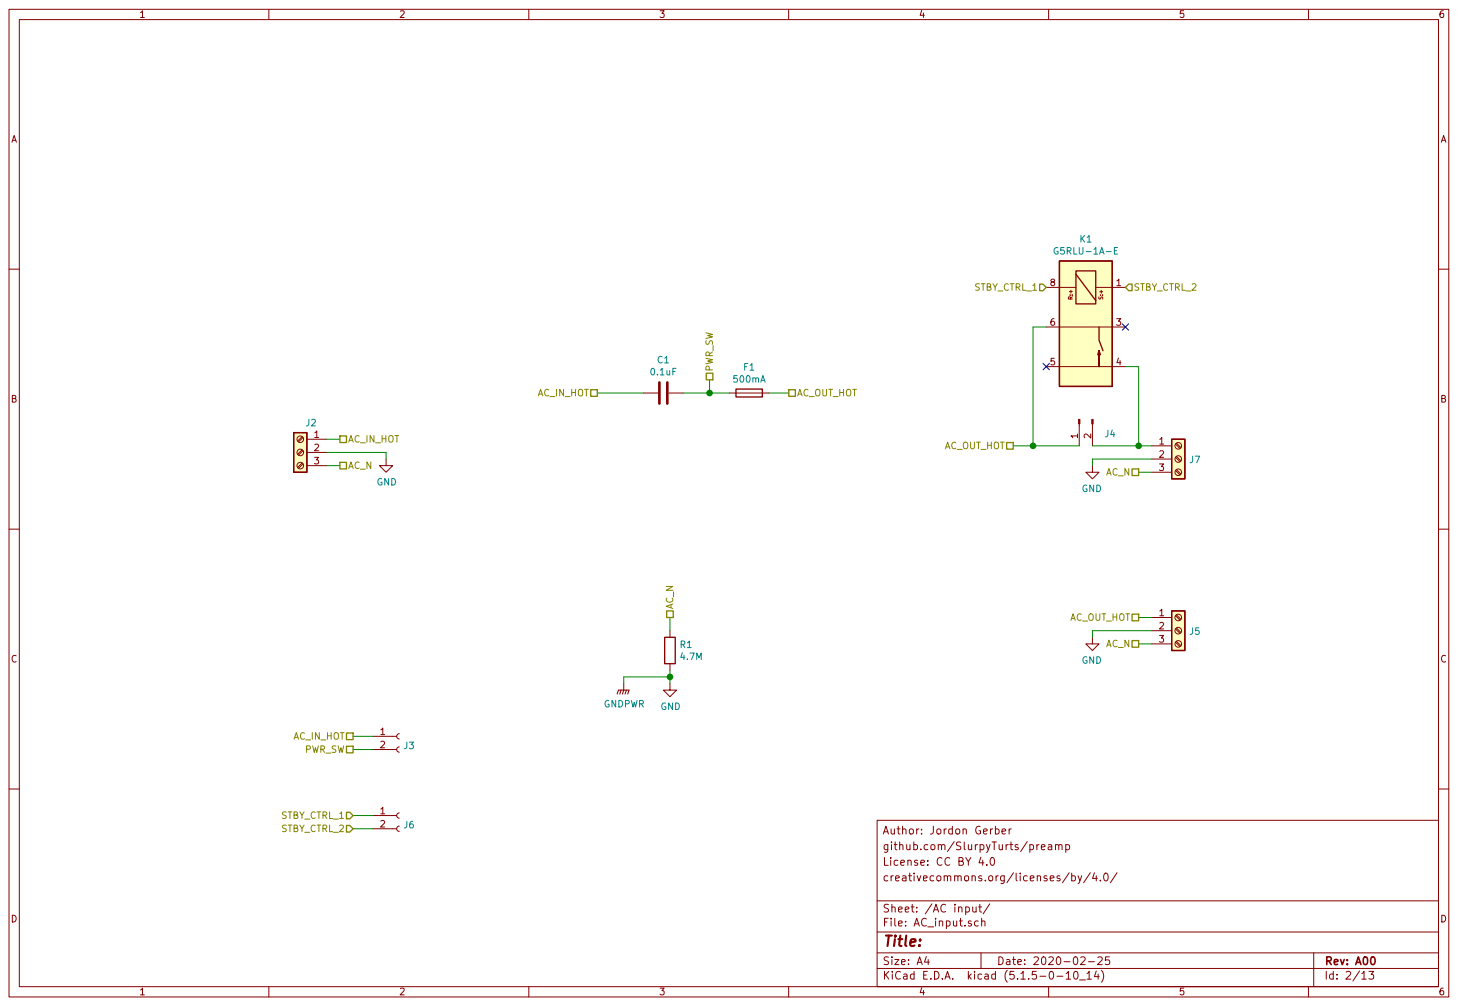
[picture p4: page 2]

github.com/SlurpyTurts/preamp Author: Jordon Gerber

creativecommons.org/licenses/by/4.0/ License: CC BY 4.0

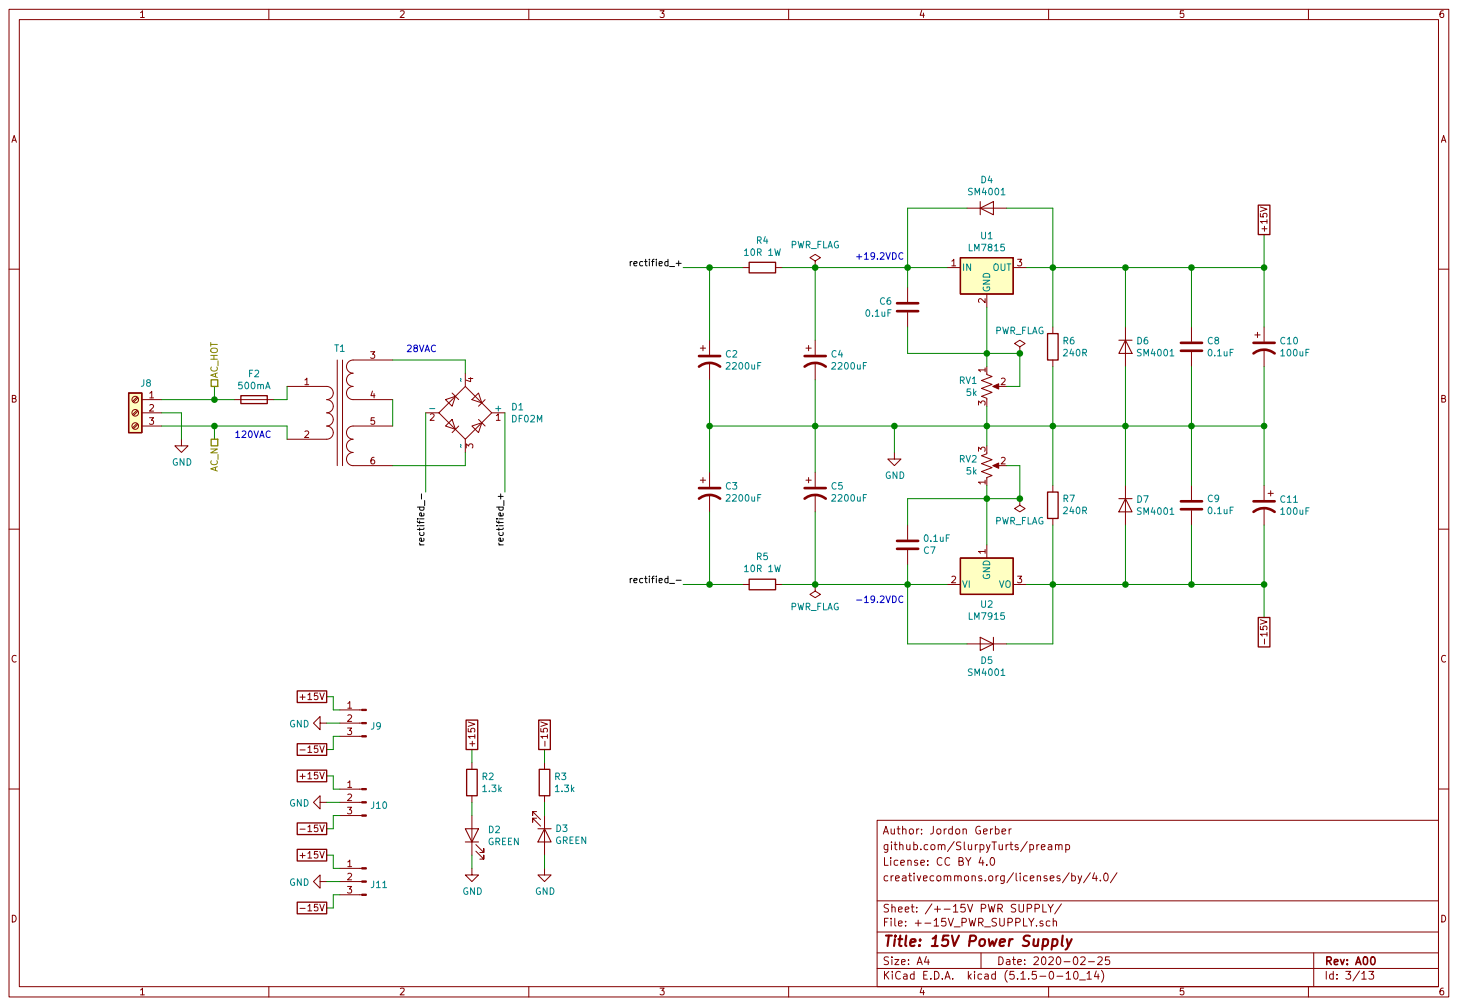
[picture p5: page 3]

1.3k D2 GREEN GND GND GND

File: +-15V_PWR_SUPPLY.sch Sheet: /+-15V PWR SUPPLY/ creativecommons.org/licenses/by/4.0/ License: CC BY 4.0

Id: 3/13 Title: 15V Power Supply

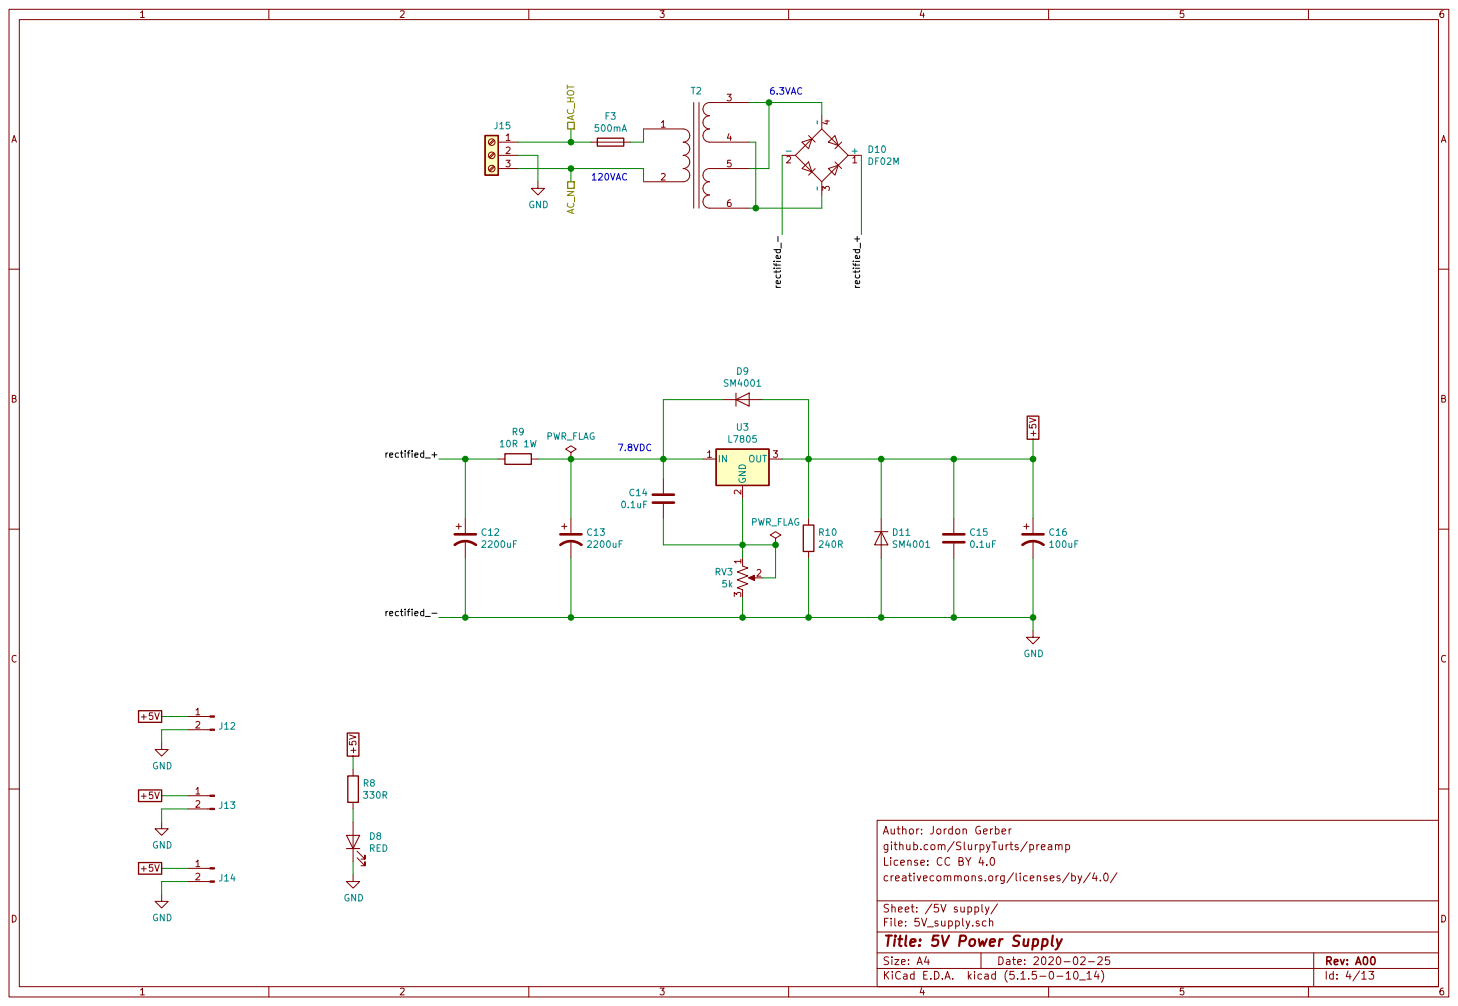
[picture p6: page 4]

github.com/SlurpyTurts/preamp Author: Jordon Gerber C15

creativecommons.org/licenses/by/4.0/ License: CC BY 4.0

Sheet: /5V supply/
File: 5V_supply.sch
Id: 4/13 Title: 5V Power Supply

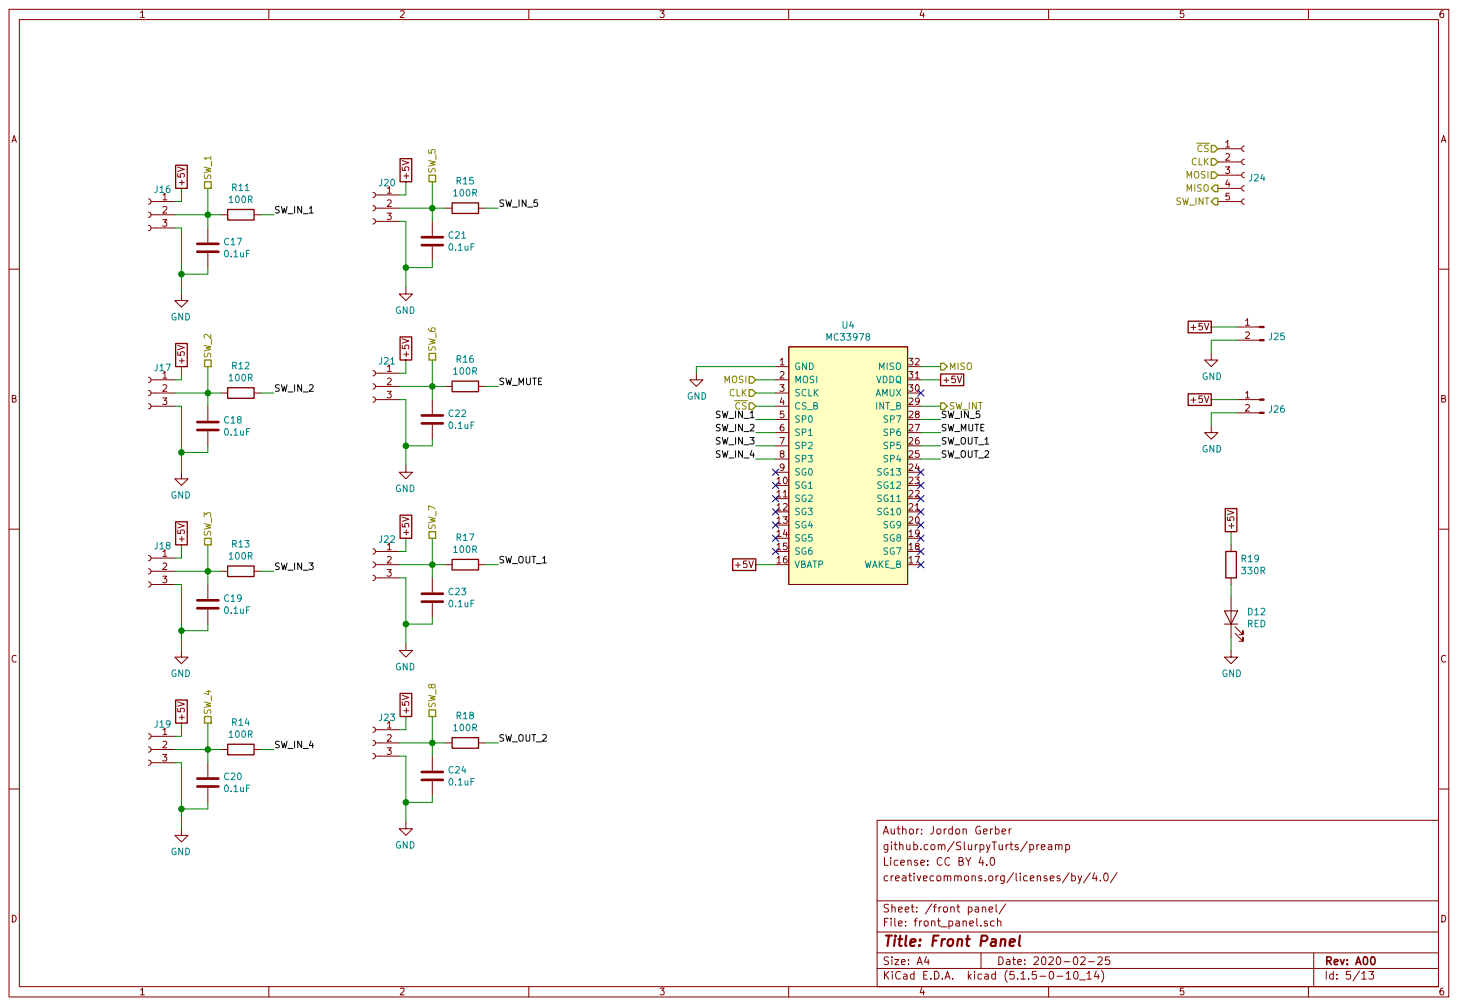
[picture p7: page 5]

creativecommons.org/licenses/by/4.0/ License: CC BY 4.0

Sheet: /front panel/
File: front_panel.sch
Id: 5/13 Title: Front Panel

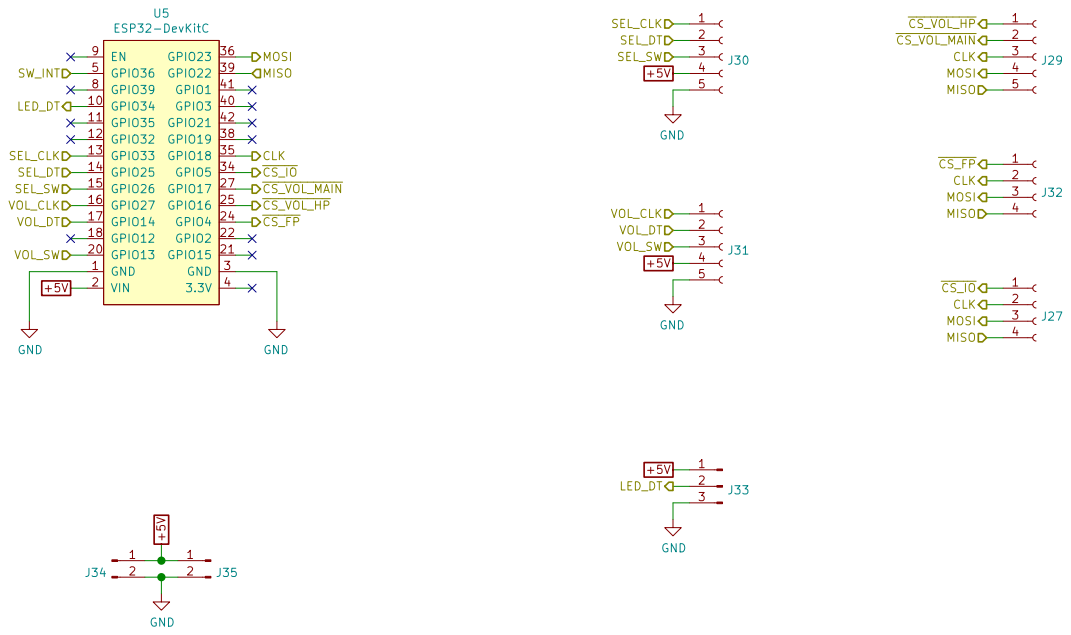
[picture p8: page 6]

File: MCU.sch Sheet: /MCU/ creativecommons.org/licenses/by/4.0/ License: CC BY 4.0

Id: 6/13 Title: Preamp MCU Board

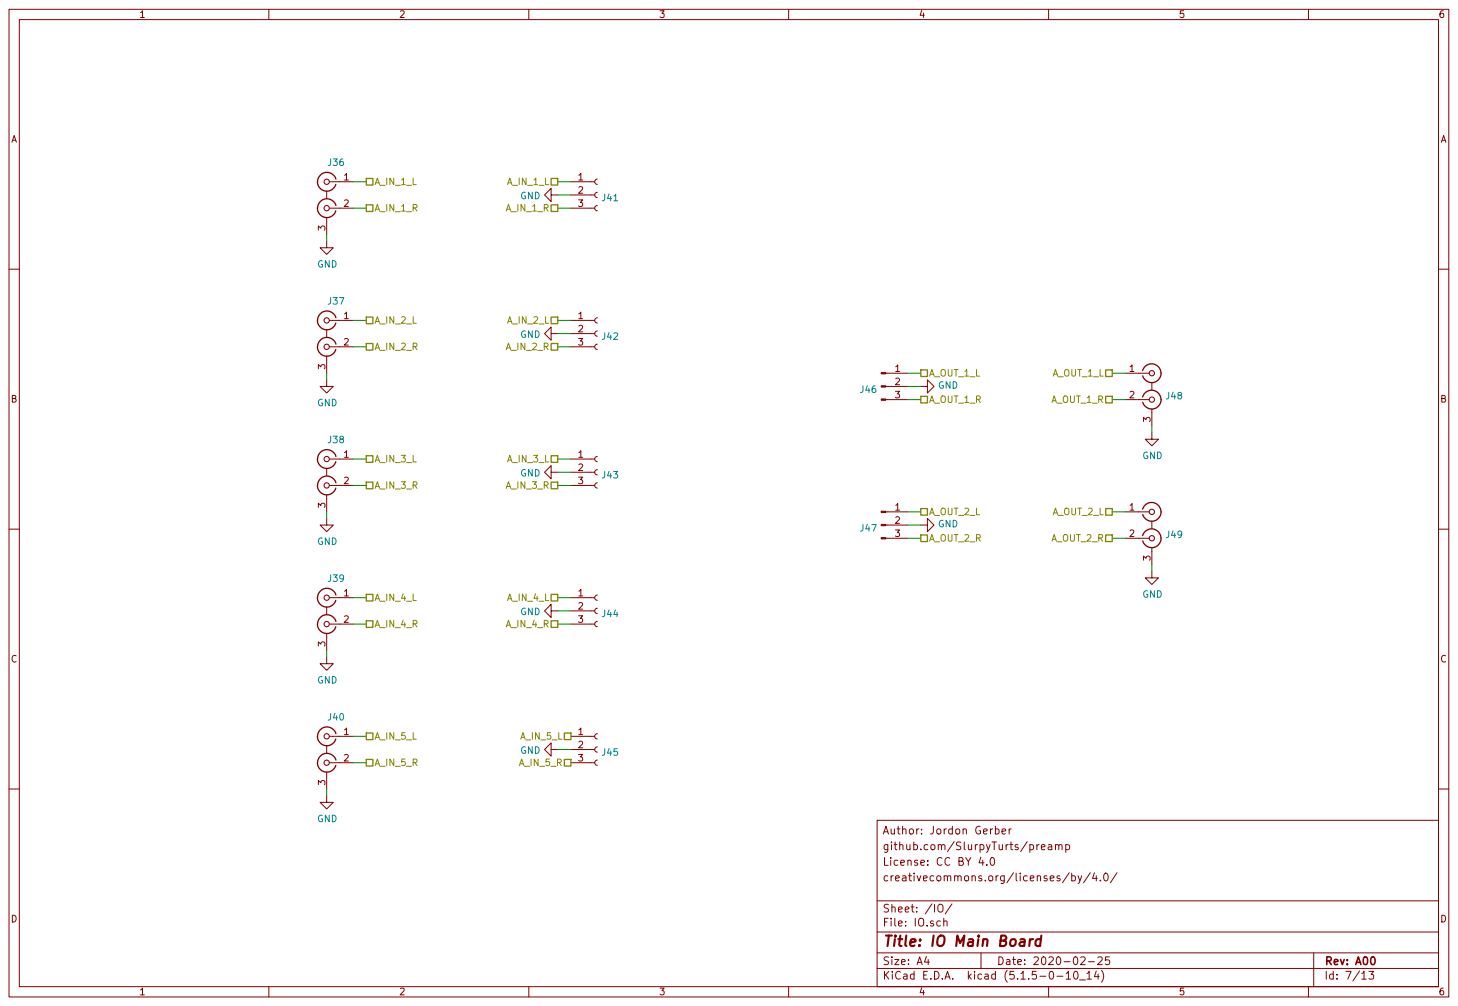
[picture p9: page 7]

File: IO.sch Sheet: /IO/ creativecommons.org/licenses/by/4.0/ License: CC BY 4.0

Id: 7/13 Title: IO Main Board

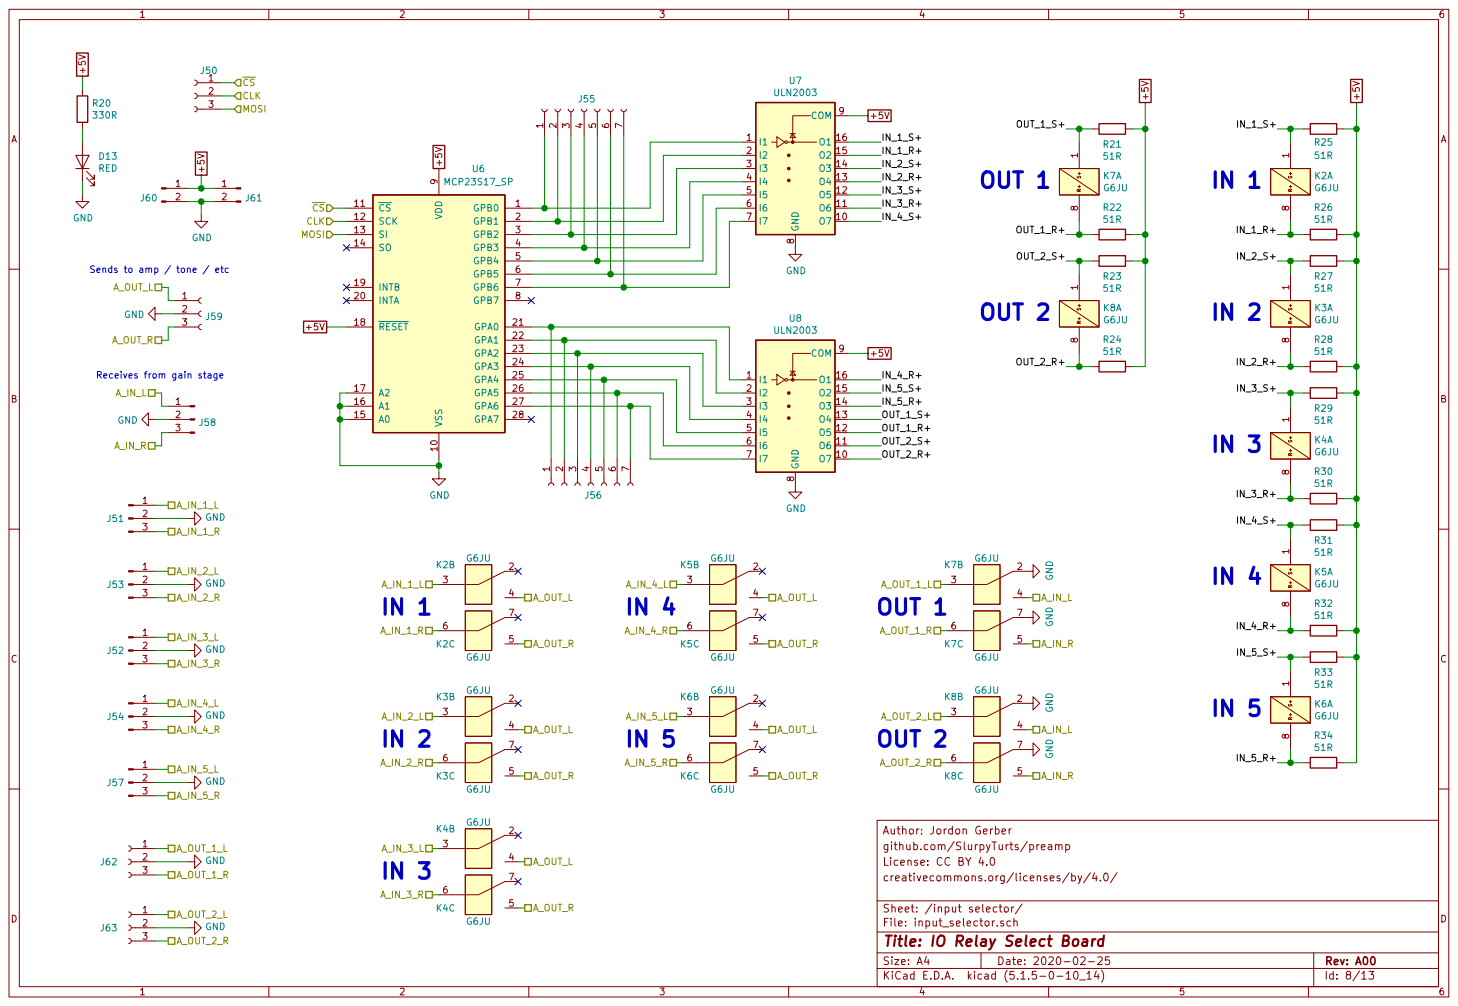
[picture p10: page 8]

Sends to amp / tone / etc

Receives from gain stage

GND GND GND

github.com/SlurpyTurts/preamp Author: Jordon Gerber

creativecommons.org/licenses/by/4.0/ License: CC BY 4.0

Sheet: /input selector/
File: input_selector.sch
Id: 8/13 Title: IO Relay Select Board

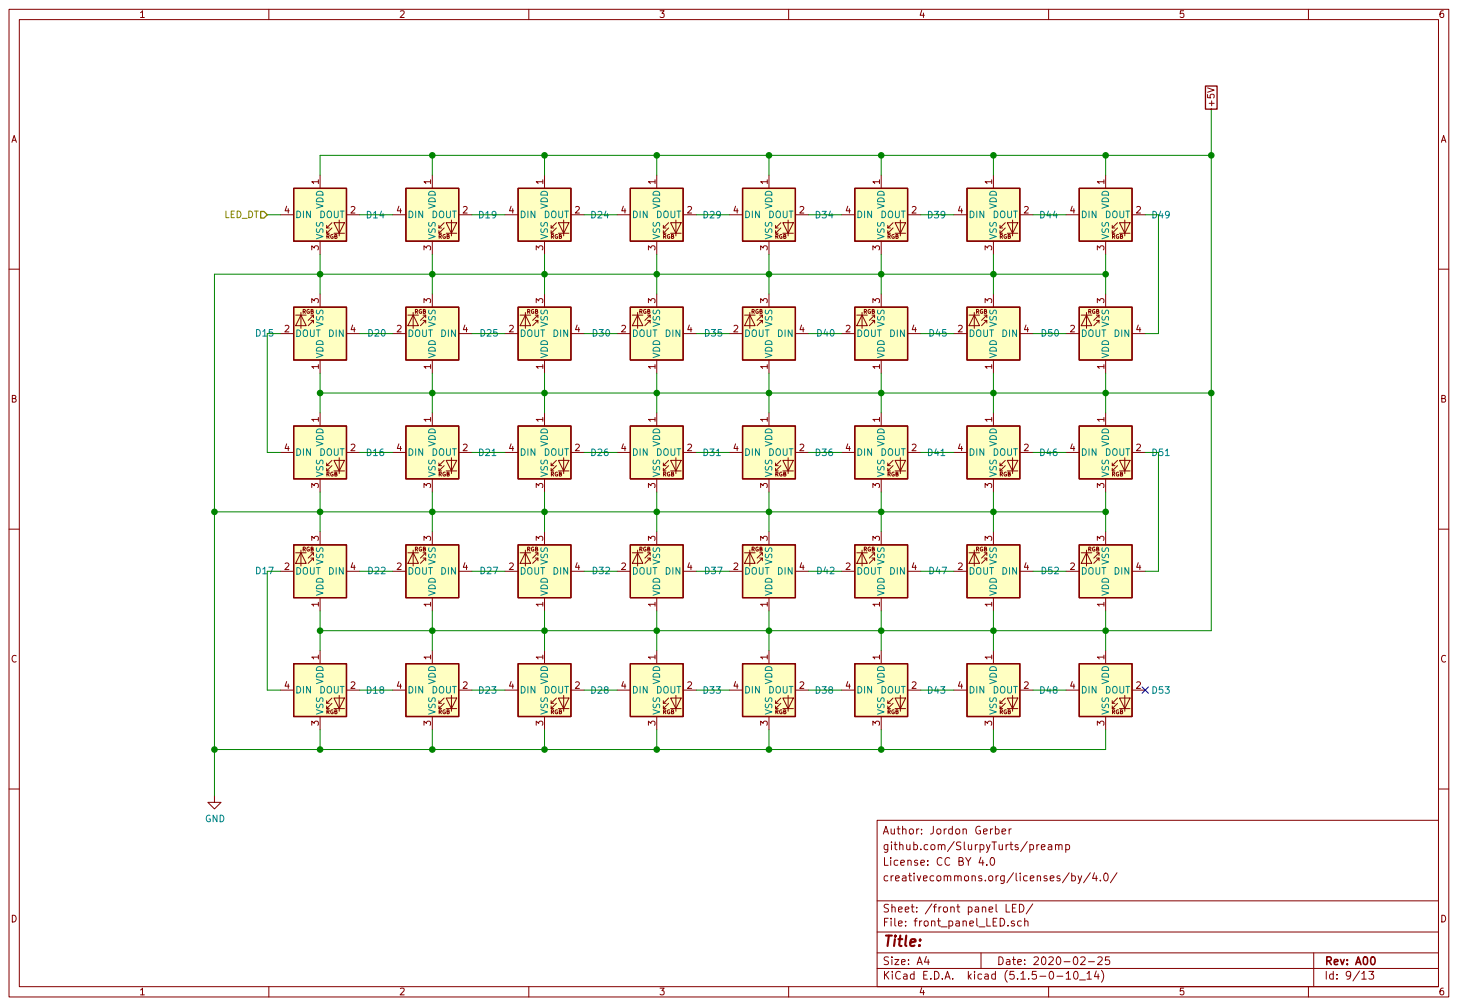
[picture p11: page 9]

github.com/SlurpyTurts/preamp Author: Jordon Gerber

creativecommons.org/licenses/by/4.0/ License: CC BY 4.0

Sheet: /front panel LED/
File: front_panel_LED.sch
Id: 9/13 Title:

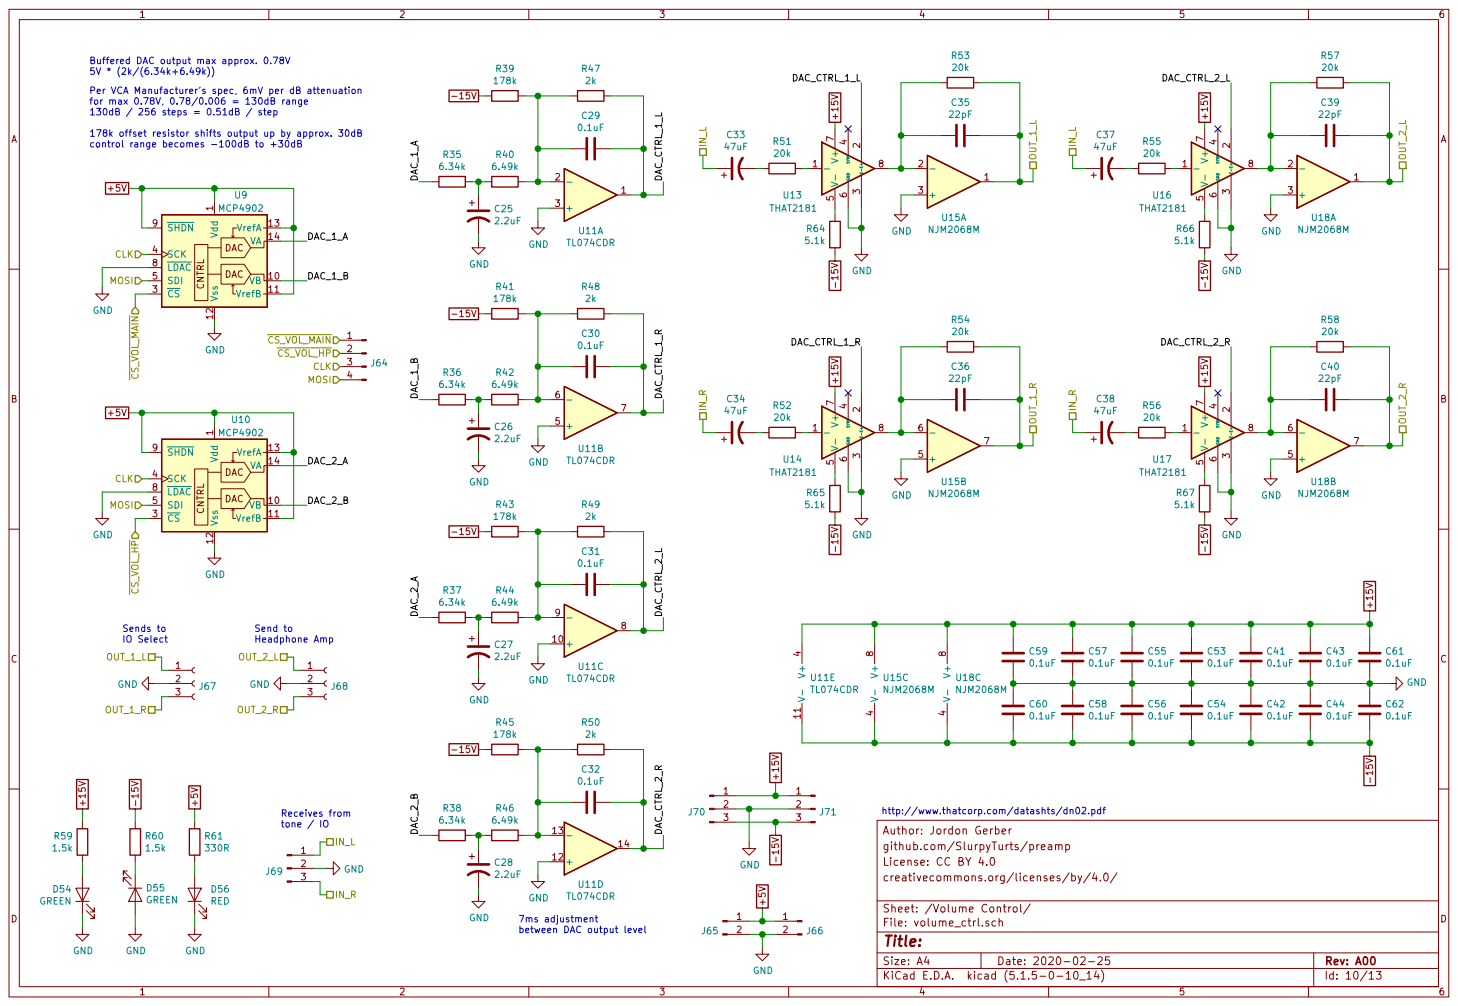
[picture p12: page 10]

Buffered DAC output max approx. 0.78V
Per VCA Manufacturers spec, 6mV per dB attenuation
for max 0.78V, 0.78/0.006 = 130dB range
130dB / 256 steps = 0.51dB / step
178k offset resistor shifts output up by approx. 30dB
control range becomes -100dB to +30dB

1 VB 10 VrefB 11 Vss 12 VrefA 13 VA 14 CS 3 SCK 4 SDI 5

Send to Headphone Amp Receives from

github.com/SlurpyTurts/preamp Author: Jordon Gerber

File: volume_ctrl.sch Sheet: /Volume Control/ creativecommons.org/licenses/by/4.0/ License: CC BY 4.0

between DAC output level


crosstalk: https://headwizememorial.wordpress.com/2018/03/09/an-acoustic-simulator-for-headphone-amplifiers/

amp: https://www.nutsvolts.com/magazine/article/precision_stereo_headphone_amplifier

github.com/SlurpyTurts/preamp Author: Jordon Gerber

creativecommons.org/licenses/by/4.0/ License: CC BY 4.0

Sheet: /headphone amp/
File: headphone_amp.sch
Id: 11/13 Title: Headphone Amplifier Board


github.com/SlurpyTurts/preamp Author: Jordon Gerber

creativecommons.org/licenses/by/4.0/ License: CC BY 4.0

Sheet: /headphone amp/Headphone Crossfeed/
File: headphone_crossfeed.sch
Id: 12/13 Title: Headphone Crosstalk


IO Select Send to

github.com/SlurpyTurts/preamp Author: Jordon Gerber

creativecommons.org/licenses/by/4.0/ License: CC BY 4.0

Sheet: /Balanced daughter IO pcb/
File: IO_BALANCED_DAUGHTER.sch
Id: 13/13 Title: Balanced IO Daughter Board

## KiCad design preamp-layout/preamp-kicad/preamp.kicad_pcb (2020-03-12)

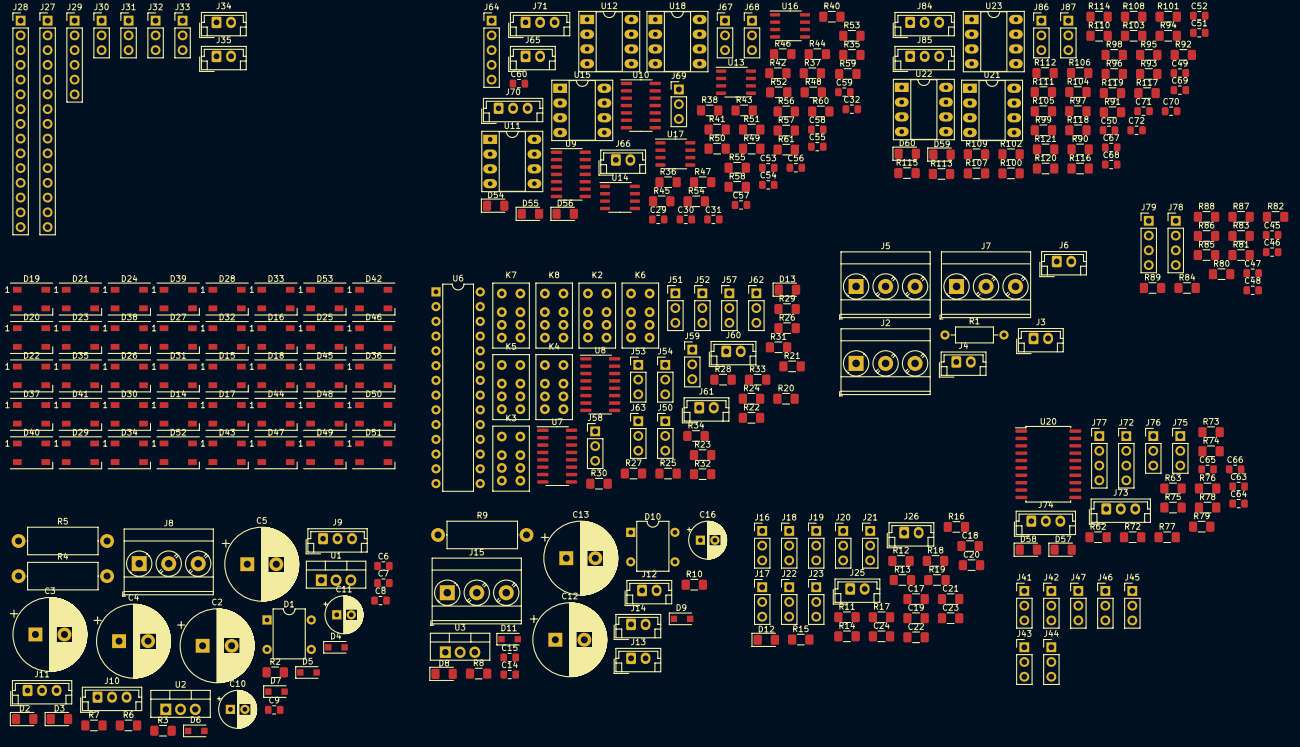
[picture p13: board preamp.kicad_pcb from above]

Board: 2 copper layers, 324 parts (0 on the bottom side), 199 nets, no tracks yet.

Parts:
C2, C3, C4, C5, C12, C13: 2200uF; CP_Radial_D12.5mm_P5.00mm
C6, C7, C8, C9, C14, C15, C29, C30, C31, C32, C53, C54, C55, C56, C57, C58, C59, C60, C63, C64, C65, C66, C67, C68, C69, C70, C71, C72: 0.1uF; C_0805_2012Metric_Pad1.15x1.40mm_HandSolder
C10, C11, C16: 100uF; CP_Radial_D6.3mm_P2.50mm
C17, C18, C19, C20, C21, C22, C23, C24: 0.1uF; C_1206_3216Metric_Pad1.42x1.75mm_HandSolder
C45, C48: 0.022uF; C_0805_2012Metric_Pad1.15x1.40mm_HandSolder
C46, C47: 0.12uF; C_0805_2012Metric_Pad1.15x1.40mm_HandSolder
C49, C50, C51, C52: 3300pF; C_0805_2012Metric_Pad1.15x1.40mm_HandSolder
D1, D10: DF02M; Diode_Bridge_DIP-4_W7.62mm_P5.08mm
D2, D3, D54, D55, D57, D58, D59, D60: GREEN; LED_1206_3216Metric_Pad1.42x1.75mm_HandSolder
D4, D5, D6, D7, D9, D11: SM4001; D_SOD-123F
D8, D12, D13, D56: RED; LED_1206_3216Metric_Pad1.42x1.75mm_HandSolder
D14, D15, D16, D17, D18, D19, D20, D21, D22, D23, D24, D25, D26, D27, D28, D29, D30, D31, D32, D33, D34, D35, D36, D37, D38, D39, D40, D41, D42, D43, D44, D45, D46, D47, D48, D49, D50, D51, D52, D53: WS2812B; LED_WS2812B_PLCC4_5.0x5.0mm_P3.2mm
J2, J5, J7, J8, J15: Screw_Terminal_01x03; TerminalBlock_Phoenix_MKDS-3-3-5.08_1x03_P5.08mm_Horizontal
J3, J6: Conn_01x02_Female; JST_EH_B2B-EH-A_1x02_P2.50mm_Vertical
J4, J12, J13, J14, J25, J26, J34, J35, J60, J61, J65, J66: Conn_01x02_Male; JST_EH_B2B-EH-A_1x02_P2.50mm_Vertical
J9, J10, J11, J70, J71, J73, J74, J84, J85: Conn_01x03_Male; JST_EH_B3B-EH-A_1x03_P2.50mm_Vertical
J16, J17, J18, J19, J20, J21, J22, J23, J30, J31, J32, J41, J42, J43, J44, J45, J50, J59, J62, J63, J67, J68, J76, J86: Conn_01x03_Female; PinHeader_1x03_P2.54mm_Vertical
J27, J28: Conn_01x15_Female; PinHeader_1x15_P2.54mm_Vertical
J29: Conn_01x06_Female; PinHeader_1x06_P2.54mm_Vertical
J33, J46, J47, J51, J52, J53, J54, J57, J58, J69, J75, J87: Conn_01x03_Male; PinHeader_1x03_P2.54mm_Vertical
J64: Conn_01x05_Male; PinHeader_1x05_P2.54mm_Vertical
J72, J79: Conn_01x04_Male; PinHeader_1x04_P2.54mm_Vertical
J77, J78: Conn_01x04_Female; PinHeader_1x04_P2.54mm_Vertical
K2, K3, K4, K5, K6, K7, K8: G6JU; Relay_DPDT_Omron_G6JU-2P-Y
R1: 4.7M; R_Axial_DIN0207_L6.3mm_D2.5mm_P10.16mm_Horizontal
R2, R3: 1.3k; R_1206_3216Metric_Pad1.42x1.75mm_HandSolder
R4, R5, R9: 10R 1W; R_Axial_DIN0414_L11.9mm_D4.5mm_P15.24mm_Horizontal
R6, R7, R10: 240R; R_1206_3216Metric_Pad1.42x1.75mm_HandSolder
R8, R19, R20, R61: 330R; R_1206_3216Metric_Pad1.42x1.75mm_HandSolder
R11, R12, R13, R14, R15, R16, R17, R18, R101, R102, R106, R117, R118, R121: 100R; R_1206_3216Metric_Pad1.42x1.75mm_HandSolder
R21, R22, R23, R24, R25, R26, R27, R28, R29, R30, R31, R32, R33, R34: 51R; R_1206_3216Metric_Pad1.42x1.75mm_HandSolder
R35, R36, R37, R38: 6.34k; R_1206_3216Metric_Pad1.42x1.75mm_HandSolder
R40, R42, R44, R46: 6.49k; R_1206_3216Metric_Pad1.42x1.75mm_HandSolder
R41, R43, R45: 178k; R_1206_3216Metric_Pad1.42x1.75mm_HandSolder
R47, R48, R49, R50: 2k; R_1206_3216Metric_Pad1.42x1.75mm_HandSolder
R51, R52, R53, R54, R55, R56, R57, R58: 20k; R_1206_3216Metric_Pad1.42x1.75mm_HandSolder
R59, R60, R62, R63, R80, R88, R100, R105: 1.5k; R_1206_3216Metric_Pad1.42x1.75mm_HandSolder
R72, R73: 50R; R_1206_3216Metric_Pad1.42x1.75mm_HandSolder
R74, R75: 500R; R_1206_3216Metric_Pad1.42x1.75mm_HandSolder
R76, R77, R81, R89, R93, R94, R110, R111: 1k; R_1206_3216Metric_Pad1.42x1.75mm_HandSolder
R78, R79: 10R; R_1206_3216Metric_Pad1.42x1.75mm_HandSolder
R82, R87: 9.1k; R_1206_3216Metric_Pad1.42x1.75mm_HandSolder
R83, R84, R85, R86: 3.3k; R_1206_3216Metric_Pad1.42x1.75mm_HandSolder
R90, R91, R92, R95, R96, R99, R103, R104, R107, R108, R109, R112, R115, R116, R119, R120: 10k; R_1206_3216Metric_Pad1.42x1.75mm_HandSolder
R97, R98, R113, R114: 9.09k; R_1206_3216Metric_Pad1.42x1.75mm_HandSolder
U1: LM7815; TO-220-3_Vertical
U2: LM7915; TO-220-3_Vertical
U3: L7805; TO-220-3_Vertical
U6: MCP23S17_SP; DIP-28_W7.62mm
U7, U8: ULN2003; SOIC-16_3.9x9.9mm_P1.27mm
U9, U10: MCP4902; SOIC-14_3.9x8.7mm_P1.27mm
U11, U12, U15, U18, U21, U22, U23: TL072; DIP-8_W7.62mm_Socket_LongPads
U13, U14, U16, U17: THAT2181; SO-8_3.9x4.9mm_P1.27mm
U20: TPA6120; SOIC-20W_7.5x12.8mm_P1.27mm

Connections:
+5V: C15.1, C16.1, D9.2, D11.1, D14.1, D15.1, D16.1, D17.1, D18.1, D19.1, D20.1, D21.1, D22.1, D23.1, D24.1, D25.1, D26.1, D27.1, D28.1, D29.1, D30.1, D31.1, D32.1, D33.1, D34.1, D35.1, D36.1, D37.1, D38.1, D39.1, D40.1, D41.1, D42.1, D43.1, D44.1, D45.1, D46.1, D47.1, D48.1, D49.1, D50.1, D51.1, D52.1, D53.1, J12.1, J13.1, J14.1, J16.1, J17.1, J18.1, J19.1, J20.1, J21.1, J22.1, J23.1, J25.1, J26.1, J27.9, J27.13, J27.15, J30.3, J31.3, J33.1, J34.1, J35.1, J60.1, J61.1, J65.1, J66.1, R8.1, R10.1, R19.1, R20.1, R21.1, R22.1, R23.1, R24.1, R25.1, R26.1, R27.1, R28.1, R29.1, R30.1, R31.1, R32.1, R33.1, R34.1, R61.1, U3.3, U6.9, U6.18, U7.9, U8.9, U9.1, U9.9, U9.11, U9.13, U10.1, U10.9, U10.11, U10.13
+15V: C8.1, C10.1, C53.1, C55.1, C57.1, C59.1, C63.1, C65.1, C67.1, C69.1, C71.1, D4.2, D6.1, J9.1, J10.1, J11.1, J70.1, J71.1, J73.1, J74.1, J77.1, J84.1, J85.1, R2.1, R6.1, R59.1, R62.1, R100.1, U1.3, U11.8, U12.8, U15.8, U18.8, U20.3, U20.18, U21.8, U22.8, U23.8
-15V: C9.1, C11.2, C54.2, C56.2, C58.2, C60.2, C64.1, C66.2, C68.2, C70.2, C72.2, D5.1, D7.2, J9.3, J10.3, J11.3, J70.3, J71.3, J73.3, J74.3, J77.2, J84.3, J85.3, R3.1, R7.1, R41.2, R43.2, R45.2, R60.1, R63.1, R105.1, U2.3, U11.4, U12.4, U13.5, U13.7, U14.5, U14.7, U15.4, U16.5, U16.7, U17.5, U17.7, U18.4, U20.1, U20.20, U21.4, U22.4, U23.4
/5V supply/rectified_+: C12.1, D10.1, R9.2
/+-15V PWR SUPPLY/AC+: J4.1, J5.1, J8.1, J15.1
/+-15V PWR SUPPLY/AC-: J2.3, J5.3, J7.3, J8.3, J15.3, R1.1
/+-15V PWR SUPPLY/rectified_+: C2.1, D1.1, R4.2
/+-15V PWR SUPPLY/rectified_-: C3.2, D1.2, R5.2
/AC input/AC_IN_+: J2.1, J3.1
/BAL_IN_L: J45.1, J57.1, J86.1, K6.3, R106.1
/BAL_IN_R: J45.3, J57.3, J86.3, K6.6, R121.1
/BAL_OUT_L: J47.1, J63.1, J87.1, K8.3, R90.2, R91.2
/BAL_OUT_R: J47.3, J63.3, J87.3, K8.6, R107.2, R108.2
/IO/A_IN_1_L: J41.1, J51.1, K2.3
/IO/A_IN_1_R: J41.3, J51.3, K2.6
/IO/A_IN_2_L: J42.1, J53.1, K3.3
/IO/A_IN_2_R: J42.3, J53.3, K3.6
/IO/A_IN_3_L: J43.1, J52.1, K4.3
/IO/A_IN_3_R: J43.3, J52.3, K4.6
/IO/A_IN_4_L: J44.1, J54.1, K5.3
/IO/A_IN_4_R: J44.3, J54.3, K5.6
/IO/A_OUT_1_L: J46.1, J62.1, K7.3
/IO/A_OUT_1_R: J46.3, J62.3, K7.6
/MCU/CLK: J28.7, J32.1
/MCU/CS_VOL_HP: J28.10, J29.3, J64.5, U10.3
/MCU/CS_VOL_MAIN: J28.9, J29.4, J64.4, U9.3
/MCU/LED_DT: D14.4, J27.4, J33.2
/MCU/MISO: J28.2, J32.3
/MCU/MOSI: J28.1, J32.2
/MCU/SEL_CLK: J27.7, J30.1
/MCU/SEL_DT: J27.8, J30.2
/MCU/VOL_CLK: J27.10, J31.1
/MCU/VOL_DT: J27.11, J31.2
/Volume Control/Buffered_DAC_HP_L: C31.1, R49.1, U12.1, U16.2
/Volume Control/Buffered_DAC_HP_R: C32.1, R50.1, U12.7, U17.2
/Volume Control/Buffered_DAC_Main_L: C29.1, R47.1, U11.1, U13.2
/Volume Control/Buffered_DAC_Main_R: C30.1, R48.1, U11.7, U14.2
/Volume Control/CLK: J64.1, U9.4, U10.4
/Volume Control/MOSI: J64.3, U9.5, U10.5
/Volume Control/~LDAC: J64.2, U9.8, U10.8
/front panel/CS: J28.11, J29.2
/front panel/SW_1: C17.1, J16.2, R11.1
/front panel/SW_2: C18.1, J17.2, R12.1
/front panel/SW_3: C19.1, J18.2, R13.1
/front panel/SW_4: C20.1, J19.2, R14.1
/front panel/SW_5: C21.1, J20.2, R15.1
/front panel/SW_6: C22.1, J21.2, R16.1
/front panel/SW_7: C23.1, J22.2, R17.1
/front panel/SW_8: C24.1, J23.2, R18.1
/headphone amp/L_IN: C45.1, J68.1, J72.1, J75.1, J78.1, R57.1, U18.1
/headphone amp/L_OUT: J76.1, R78.1
/headphone amp/R_IN: C48.1, J68.3, J72.3, J75.3, J78.3, R58.1, U18.7
/headphone amp/R_OUT: J76.3, R79.1
/headphone amp/xfeed_out_l: J72.2, J78.2, R72.2, R80.2, R81.1, R82.2, R85.2
/headphone amp/xfeed_out_r: J72.4, J78.4, R73.2, R84.2, R87.2, R88.2, R89.1
/input selector/A_IN_L: J58.1, J67.1, K7.4, K8.4, R53.1, U15.1
/input selector/A_IN_R: J58.3, J67.3, K7.5, K8.5, R54.1, U15.7
/input selector/A_OUT_L: J59.1, J69.3, K2.4, K3.4, K4.4, K5.4, K6.4
/input selector/A_OUT_R: J59.3, J69.1, K2.5, K3.5, K4.5, K5.5, K6.5
/input selector/CLK: J50.2, U6.12
/input selector/CS: J28.8, J29.1, J50.1, U6.11
/input selector/IN_1_R+: K2.8, R26.2, U7.15
/input selector/IN_1_S+: K2.1, R25.2, U7.16
/input selector/IN_2_R+: K3.8, R28.2, U7.13
/input selector/IN_2_S+: K3.1, R27.2, U7.14
/input selector/IN_3_R+: K4.8, R30.2, U7.11
/input selector/IN_3_S+: K4.1, R29.2, U7.12
/input selector/IN_4_R+: K5.8, R32.2, U8.16
/input selector/IN_4_S+: K5.1, R31.2, U7.10
/input selector/IN_5_R+: K6.8, R34.2, U8.14
/input selector/IN_5_S+: K6.1, R33.2, U8.15
/input selector/MOSI: J50.3, U6.13
/input selector/OUT_1_R+: K7.8, R22.2, U8.12
/input selector/OUT_1_S+: K7.1, R21.2, U8.13
/input selector/OUT_2_R+: K8.8, R24.2, U8.10
/input selector/OUT_2_S+: K8.1, R23.2, U8.11
GND: C2.2, C3.1, C4.2, C5.1, C8.2, C9.2, C10.2, C11.1, C12.2, C13.2, C15.2, C16.2, C17.2, C18.2, C19.2, C20.2, C21.2, C22.2, C23.2, C24.2, C46.2, C47.2, C49.2, C50.1, C51.2, C52.1, C53.2, C54.1, C55.2, C56.1, C57.2, C58.1, C59.2, C60.1, C63.2, C64.2, C65.2, C66.1, C67.2, C68.1, C69.2, C70.1, C71.2, C72.1, D2.1, D3.2, D6.2, D7.1, D8.1, D10.2, D11.2, D12.1, D13.1, D14.3, D15.3, D16.3, D17.3, D18.3, D19.3, D20.3, D21.3, D22.3, D23.3, D24.3, D25.3, D26.3, D27.3, D28.3, D29.3, D30.3, D31.3, D32.3, D33.3, D34.3, D35.3, D36.3, D37.3, D38.3, D39.3, D40.3, D41.3, D42.3, D43.3, D44.3, D45.3, D46.3, D47.3, D48.3, D49.3, D50.3, D51.3, D52.3, D53.3, D54.1, D55.2, D56.1, D57.1, D58.2, D59.1, D60.2, J2.2, J5.2, J7.2, J8.2, J9.2, J10.2, J11.2, J12.2, J13.2, J14.2, J15.2, J16.3, J17.3, J18.3, J19.3, J20.3, J21.3, J22.3, J23.3, J25.2, J26.2, J27.14, J33.3, J34.2, J35.2, J41.2, J42.2, J43.2, J44.2, J45.2, J46.2, J47.2, J51.2, J52.2, J53.2, J54.2, J57.2, J58.2, J59.2, J60.2, J61.2, J62.2, J63.2, J65.2, J66.2, J67.2, J68.2, J69.2, J70.2, J71.2, J73.2, J74.2, J75.2, J76.2, J77.3, J79.3, J84.2, J85.2, J86.2, J87.2, K7.2, K7.7, K8.2, K8.7, R1.2, R6.2, R7.2, R10.2, R74.2, R75.2, R81.2, R89.2, R92.2, R95.2, R104.1, R109.2, R112.2, R120.1, U6.10, U6.15, U6.16, U6.17, U7.8, U8.8, U9.12, U10.12, U11.3, U11.5, U12.3, U12.5, U13.3, U13.6, U14.3, U14.6, U15.3, U15.5, U16.3, U16.6, U17.3, U17.6, U18.3, U18.5, U22.5, U23.5
unnamed: C4.1, C6.1, D4.1, R4.1, U1.1
unnamed: C5.2, C7.1, D5.2, R5.1, U2.2
unnamed: C6.2, U1.2
unnamed: C7.2, U2.1
unnamed: C13.1, C14.1, D9.1, R9.1, U3.1
unnamed: C14.2, U3.2
unnamed: R35.1, R40.2
unnamed: R36.1, R42.2
unnamed: R37.1, R44.2
unnamed: R38.1, R46.2
unnamed: C29.2, R40.1, R47.2, U11.2
unnamed: C30.2, R41.1, R42.1, R48.2, U11.6
unnamed: C31.2, R43.1, R44.1, R49.2, U12.2
unnamed: C32.2, R45.1, R46.1, R50.2, U12.6
unnamed: R53.2, U13.8, U15.2
unnamed: R54.2, U14.8, U15.6
unnamed: R57.2, U16.8, U18.2
unnamed: R58.2, U17.8, U18.6
unnamed: C45.2, R82.1
unnamed: C46.1, R83.2, R84.1
unnamed: C47.1, R85.1, R86.2
unnamed: C48.2, R87.1
unnamed: C49.1, R93.1, R97.2
unnamed: C50.2, R94.1, R98.2
unnamed: C51.1, R110.1, R113.2
unnamed: C52.2, R111.1, R114.2
unnamed: D2.2, R2.2
unnamed: D3.1, R3.2
unnamed: D8.2, R8.2
unnamed: D12.2, R19.2
unnamed: D13.2, R20.2
unnamed: D14.2, D19.4
unnamed: D15.2, D16.4
unnamed: D15.4, D20.2
unnamed: D16.2, D21.4
unnamed: D17.2, D18.4
unnamed: D17.4, D22.2
unnamed: D18.2, D23.4
unnamed: D19.2, D24.4
unnamed: D20.4, D25.2
unnamed: D21.2, D26.4
unnamed: D22.4, D27.2
unnamed: D23.2, D28.4
unnamed: D24.2, D29.4
unnamed: D25.4, D30.2
unnamed: D26.2, D31.4
unnamed: D27.4, D32.2
unnamed: D28.2, D33.4
unnamed: D29.2, D34.4
unnamed: D30.4, D35.2
unnamed: D31.2, D36.4
unnamed: D32.4, D37.2
unnamed: D33.2, D38.4
unnamed: D34.2, D39.4
unnamed: D35.4, D40.2
unnamed: D36.2, D41.4
unnamed: D37.4, D42.2
unnamed: D38.2, D43.4
unnamed: D39.2, D44.4
unnamed: D40.4, D45.2
unnamed: D41.2, D46.4
unnamed: D42.4, D47.2
unnamed: D43.2, D48.4
unnamed: D44.2, D49.4
unnamed: D45.4, D50.2
unnamed: D46.2, D51.4
unnamed: D47.4, D52.2
unnamed: D48.2, D53.4
unnamed: D49.2, D50.4
unnamed: D51.2, D52.4
unnamed: D54.2, R59.2
unnamed: D55.1, R60.2
unnamed: D56.2, R61.2
unnamed: D57.2, R62.2
unnamed: D58.1, R63.2
unnamed: D59.2, R100.2
unnamed: D60.1, R105.2
unnamed: J4.2, J7.1
unnamed: U6.1, U7.1
unnamed: U6.2, U7.2
unnamed: U6.3, U7.3
unnamed: U6.4, U7.4
unnamed: U6.5, U7.5
unnamed: U6.6, U7.6
unnamed: U6.7, U7.7
unnamed: U6.21, U8.1
unnamed: U6.22, U8.2
unnamed: U6.23, U8.3
unnamed: U6.24, U8.4
unnamed: U6.25, U8.5
unnamed: U6.26, U8.6
unnamed: U6.27, U8.7
unnamed: R35.2, U9.14
unnamed: R36.2, U9.10
unnamed: R37.2, U10.14
unnamed: R38.2, U10.10
unnamed: R51.1, U13.1
unnamed: R52.1, U14.1
unnamed: R55.1, U16.1
unnamed: R56.1, U17.1
unnamed: R72.1, R76.2, U20.5
unnamed: R73.1, R77.2, U20.16
unnamed: R74.1, U20.4
unnamed: R75.1, U20.17
unnamed: R76.1, R78.2, U20.2
unnamed: R77.1, R79.2, U20.19
unnamed: R90.1, R92.1, U22.3
unnamed: R91.1, R96.2, U22.6
unnamed: R95.1, R99.2, U22.2
unnamed: R96.1, R101.2, U22.7
unnamed: R99.1, R102.2, U22.1
unnamed: R103.1, R106.2, U21.1
unnamed: R97.1, R103.2, U21.2
unnamed: R98.1, R104.2, U21.3
unnamed: R107.1, R109.1, U23.3
unnamed: R108.1, R116.2, U23.6
unnamed: R112.1, R115.2, U23.2
unnamed: R113.1, R119.2, U21.6
unnamed: R114.1, R120.2, U21.5
unnamed: R115.1, R117.2, U23.1
unnamed: R116.1, R118.2, U23.7
unnamed: R119.1, R121.2, U21.7

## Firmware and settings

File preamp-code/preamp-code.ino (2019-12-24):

/*
 * When configured for DOIT ESP32, GPIO pins are assigned as the pin number (GPIO4 is pin 4)
 * When configured for ESP8266 NodeMCU, GPIO pins are assigned as the pin label according to the silkscreen on the PCB (defining a pin by D4 correlates to D4 on the board) 
 * currently configured for DOIT ESP32 DEVKIT V1 board
 * 
 */

#include <EEPROM.h>
#include "Preamp.h"
#include <SPI.h>

SPIClass IO_Expand(VSPI);

//preamp IO ports
#define NUM_INPUTS 6
#define NUM_OUTPUTS 1

//assigning EEPROM locations
#define EEPROM_SIZE 4
#define VOLUME_STORE 0
#define INPUT_STORE 1
#define OUTPUT_STORE 2
#define MUTE_STORE 3

//assigning encoder pins
#define VOL_CLK 27
#define VOL_DT 14
#define VOL_SW 13

#define SEL_CLK 33
#define SEL_DT 25
#define SEL_SW 26

#define NUM_LEDS 60
#define LED_PIN 16

Preamp preamp(NUM_INPUTS, NUM_OUTPUTS, new Encoder(VOL_CLK, VOL_DT, VOL_SW), new Encoder(SEL_CLK, SEL_DT, SEL_SW), new Adafruit_NeoPixel(60, 16, NEO_GRB + NEO_KHZ800));

enum Actions{vol_up, vol_down, vol_set, sel_next, sel_prev, sel_set, toggle_mute};
Actions action;

int vol, input, output = 0; //for assigning values to the preamp

//------------------------INPUT SWITCHES------------------------
//this will eventually be replaced by an SPI connection with an additional flag line to say that somethign has changed. CHIP NUMBER ______
Switch inputSelectSwitch[NUM_INPUTS];
const int inputSwitches[] = {15, 2};

//------------------------DELAYS------------------------
const int debounce_delay = 20; //microseconds. This is used in the encoder interrupt methods
const int volume_select_delay = 10; //milliseconds. This is used in the main loop switch case
const int io_select_delay = 100; //milliseconds. This is used in the main loop switch case

//------------------------INTERRUPTS------------------------
//this is required for interrupts to work in ESP8266 / ESP32, unable to find reliable documentation as to why. This specifies that the routine is put in RAM
void ICACHE_RAM_ATTR SELECT_CW_INTERRUPT(), SELECT_CCW_INTERRUPT(), SELECT_SWITCH_INTERRUPT();
void ICACHE_RAM_ATTR VOLUME_CW_INTERRUPT(), VOLUME_CCW_INTERRUPT(),VOLUME_SW_INTERRUPT();

void ICACHE_RAM_ATTR SELECT_INPUT_INTERRUPT();

bool CLK_set, DT_set = false;

void setup(){

  EEPROM.begin(EEPROM_SIZE);

  //pinMode(5, OUTPUT);
  //IO_Expand.begin(18, 23, 19, 5);
  
  //initializing preamp from EEPROM stored values
  preamp.setVolume(EEPROM.read(VOLUME_STORE));
  preamp.setInput(EEPROM.read(INPUT_STORE));
  preamp.setOutput(EEPROM.read(OUTPUT_STORE));
  preamp.setMute(EEPROM.read(MUTE_STORE));

  //attach interrupts to all controls going in to MCU (encoders, switches, IR, wifi)
  attachInterrupt(digitalPinToInterrupt(preamp.get_selector_encoder_CLKPIN()), SELECT_CW_INTERRUPT, CHANGE);
  attachInterrupt(digitalPinToInterrupt(preamp.get_selector_encoder_DTPIN()), SELECT_CCW_INTERRUPT, CHANGE);
  attachInterrupt(digitalPinToInterrupt(preamp.get_selector_encoder_SWPIN()), SELECT_SWITCH_INTERRUPT, RISING);
  
  attachInterrupt(digitalPinToInterrupt(preamp.get_volume_encoder_CLKPIN()), VOLUME_CW_INTERRUPT, CHANGE);
  attachInterrupt(digitalPinToInterrupt(preamp.get_volume_encoder_DTPIN()), VOLUME_CCW_INTERRUPT, CHANGE);
  attachInterrupt(digitalPinToInterrupt(preamp.get_volume_encoder_SWPIN()), VOLUME_SWITCH_INTERRUPT, RISING);

  for(int i = 0; i < NUM_INPUTS; i++){
    inputSelectSwitch[i].configure(inputSwitches[i], HIGH);
    attachInterrupt(digitalPinToInterrupt(inputSelectSwitch[i].getPin()), SELECT_INPUT_INTERRUPT, RISING);
  }
 
  preamp.startup();
  
}

void loop(){

  if(preamp.status_change){
    switch(action){
      case vol_up:
        preamp.volume_up();
        EEPROM.write(VOLUME_STORE, preamp.getVolume());
        EEPROM.commit();
        delay(volume_select_delay);
        break;
      case vol_down:
        preamp.volume_down();
        EEPROM.write(VOLUME_STORE, preamp.getVolume());
        EEPROM.commit();
        delay(volume_select_delay);
        break;
      case vol_set:
        preamp.setVolume(vol);
        EEPROM.write(VOLUME_STORE, preamp.getVolume());
        EEPROM.commit();
        delay(volume_select_delay);
        break;
      case sel_prev:
        preamp.select_previous();
        EEPROM.write(INPUT_STORE, preamp.getInput());
        EEPROM.commit();
        delay(io_select_delay);
        break;
      case sel_next:
        preamp.select_next();
        EEPROM.write(INPUT_STORE, preamp.getInput());
        EEPROM.commit();
        delay(io_select_delay);
        break;
      case sel_set:
        preamp.setInput(input);
        EEPROM.write(INPUT_STORE, preamp.getInput());
        EEPROM.commit();
        delay(io_select_delay);
        break;
      case toggle_mute:
        preamp.toggle_mute();
        EEPROM.write(MUTE_STORE, preamp.isMute());
        EEPROM.commit();
        delay(io_select_delay);
        break;
    }
    
    preamp.status_change = false;
  }
}


//--------------------------SELECT ENCODER--------------------------

void SELECT_CW_INTERRUPT(){
  delayMicroseconds(debounce_delay);
  if(digitalRead(preamp.get_selector_encoder_CLKPIN()) != CLK_set){
    CLK_set = !CLK_set;
    if(CLK_set && !DT_set){
      action = sel_next;
      preamp.status_change = true;
    }
  }
}

void SELECT_CCW_INTERRUPT(){
  delayMicroseconds(debounce_delay);
  if(digitalRead(preamp.get_selector_encoder_DTPIN()) != DT_set){
    DT_set = !DT_set;
    if(DT_set && !CLK_set){
      action = sel_prev;
      preamp.status_change = true;
    }
  }
}

void SELECT_SWITCH_INTERRUPT(){
//  delayMicroseconds(debounce_delay);
//  if(digitalRead(preamp.get_selector_encoder_SWPIN()) == LOW){
    action = toggle_mute;
    preamp.status_change = true;
//  }
}


//---------------------VOLUME ENCODER--------------------------

void VOLUME_CW_INTERRUPT(){
  delayMicroseconds(debounce_delay);
  if(digitalRead(preamp.get_volume_encoder_CLKPIN()) != CLK_set){
    CLK_set = !CLK_set;
    if(CLK_set && !DT_set){
      action = vol_up;
      preamp.status_change = true;
    }
  }
}

void VOLUME_CCW_INTERRUPT(){
  delayMicroseconds(debounce_delay);
  if(digitalRead(preamp.get_volume_encoder_DTPIN()) != DT_set){
    DT_set = !DT_set;
    if(DT_set && !CLK_set){
      action = vol_down;
      preamp.status_change = true;
    }
  }
}

void VOLUME_SWITCH_INTERRUPT(){
//  delayMicroseconds(debounce_delay);
//  if(digitalRead(preamp.get_volume_encoder_SWPIN()) == LOW){
    action = toggle_mute;
    preamp.status_change = true;
//  }
}



//--------------------------CAPACITIVE SWITCHES--------------------------

void SELECT_INPUT_INTERRUPT(){
  for(int i = 0; i < NUM_INPUTS; i++){
    if(inputSelectSwitch[i].is_pressed())
      input = i;
      action = sel_set;
      preamp.status_change = true;
      break;
  }
}

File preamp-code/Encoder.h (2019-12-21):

#include "Switch.h"
class Encoder{

  public:

    Encoder(int CLK, int DT, int SW){
      
      Clock->configure(CLK, HIGH);
      Data->configure(DT, HIGH);
      Button->configure(SW, HIGH);
      
      set_rotary_positions(0);
      set_switch_positions(0);
    }
    
    Encoder(int CLK, int DT, int SW, int rotary_positions, int switch_positions){
      
      Clock->configure(CLK, HIGH);
      Data->configure(DT, HIGH);
      Button->configure(SW, HIGH);
      
      set_rotary_positions(rotary_positions);
      set_switch_positions(switch_positions);
    }

    void set_CLK_pin(int pin){Clock->configure(pin, HIGH);}
    void set_DT_pin(int pin){Data->configure(pin, HIGH);}
    void set_SW_pin(int pin){Button->configure(pin, HIGH);}

    void set_rotary_positions(int positions){rotary_positions = positions;}
    void set_switch_positions(int positions){switch_positions = positions;}

    int getCLK(){return Clock->getPin();}
    int getDT(){return Data->getPin();}
    int getSW(){return Button->getPin();}

    int get_CLK_status(){return Clock->getCurrentStatus();}
    int get_DT_status(){return Data->getCurrentStatus();}
    int get_SW_status(){return Button->getCurrentStatus();}

    int get_CLK_status_prev(){return Clock->getPrevStatus();}
    int get_DT_status_prev(){return Data->getPrevStatus();}
    int get_SW_status_prev(){return Button->getPrevStatus();}

    int get_current_rotary_position(){return current_rotary_position;}
    int get_rotary_positions(){return rotary_positions;}

    int get_current_switch_position(){return current_switch_position;}
    int get_switch_positions(){return switch_positions;}

    void rotate_CW(){
      if(current_rotary_position + 1 == rotary_positions)
        current_rotary_position = 0;
      else
        current_rotary_position++;
    }
    
    void rotate_CCW(){
      if(current_rotary_position == 0)
        current_rotary_position = rotary_positions - 1;
      else
        current_rotary_position--;
    }

    void select(){
      if(current_switch_position + 1 == switch_positions)
        current_switch_position = 0;
      else
        current_switch_position++;
    }
    
    bool pressed(){
      if(Button->is_pressed())
        return true;
      return false;
    }

    bool short_pressed(){return short_press;}
    bool long_pressed(){return long_press;}

  private:

    Switch *Clock = new Switch();
    Switch *Data = new Switch();
    Switch *Button = new Switch();

    int current_rotary_position = 0;
    int rotary_positions = 0;

    int current_switch_position = 0;
    int switch_positions = 0;

    int long_press_duration = 1000000;
    bool long_press = false;
    bool short_press = false;

};

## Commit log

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2019-12-10 Moved kicad project and files to a new location. Updated readme. Added block diagram of digital / analog circuitry
    [+-15V_PWR_SUPPLY.sch, 5V_supply.sch, AC_input.sch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]
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2019-12-13 BOM skeleton added. gitignore updated to ignore schematic bak files. General work done on the schematic layout.
    [+-15V_PWR_SUPPLY.sch, 5V_supply.sch, AC_input.sch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]
2019-12-13 readme references update. preamp-code updated to implement interrupts for encoder input. Layout general updates
    [+-15V_PWR_SUPPLY.sch, 5V_supply.sch, AC_input.sch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]
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2019-12-21 Started filling in BOM. Encoder.h changed by removing number of rotary / switch positions from constructor. preamp-code.ino completely redone to implement Preamp.h.
    [preamp BOM.ods]
2019-12-24 Replaced FastLED with Adafruit_Neopixel library for controlling Neopixel display strip because FastLED and HW SPI don't play well together. Continuing to walk through SPI.
    [Preamp.h, preamp-code.ino]
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2019-12-31 IO layout cleanup
    Changed location of bal/unbal buffers from selector board to daughter board. Generalized IO PCB to accept daughter boards, not specific to connector type or bal/unbal. The idea is that as many unbala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
    [+-15V_PWR_SUPPLY.sch, 5V_supply.sch, AC_input.sch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]
2019-12-31 Encoder, LED, front panel update
    Removed hierarchical sheets for encoders, moved encoders to main sheet. Added switches for output select on front panel sheet. Added LEDs on front panel sheet but only as a symbol, only two instances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
    [+-15V_PWR_SUPPLY.sch, 5V_supply.sch, AC_input.sch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]
2019-12-31 Tone Control update
    Generated analog tone controls controlled either by pots mounted on the front panel or encoders mounted on the front panel that communicate to the tone control board via SPI.
    [+-15V_PWR_SUPPLY.sch, 5V_supply.sch, AC_input.sch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]
2020-01-10 Updates
    Minor Readme updates.
    Schematic:
    - Bus connector lines replaced single wire connectors
    - Title block populated.
    - Power Supply updates.
    - Preliminary Front Panel.
    - Minor MCU work.
    -
    [+-15V_PWR_SUPPLY.sch, 5V_supply.sch, AC_input.sch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]
2020-01-13 Added preliminary gain stage
    Gain stage added with choice of 6db or 12db gain. Cleaned up Gain stage IO pins on preamp sheet. Broke out volume ctrl to its own board, updated accordingly. Minor routing changes on preamp sheet.
    [+-15V_PWR_SUPPLY.sch, 5V_supply.sch, AC_input.sch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]
2020-01-16 VCA gain control
    Removed MDAC volume control and gain stage, replaced with VCA gain stage.
    [+-15V_PWR_SUPPLY.sch, 5V_supply.sch, AC_input.sch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]
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2020-01-19 Created component library, changed connector pinouts
    Project library was created for this project to house custom parts, starting with Omron relay. 15V supply conn output changed so that pin 1 remains +15V, but pin 2 is now common and pin 3 is now -15V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
    Implemented new schematic symbol for relays, general sheet cleanup. Removed MISO from IO selector board.
    [+-15V_PWR_SUPPLY.sch, IO.sch, IO_BALANCED_DAUGHTER.sch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]
2020-01-19 Library update, MCU config
    preliminary config of MCU with newly created ESP32 symbol in project library.
    [+-15V_PWR_SUPPLY.sch, IO_BALANCED_DAUGHTER.sch, MCU.sch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]
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2020-01-21 Grounds cleaned up, initial refdes numbering, error correction
    GNDA, GNDS, GNDD, GND all combined to GND. No point in having separate grounds for this design.
    Initial refdes numbering done using auto numbering feature. Error detection run and multple issues found which prompted Ground fix, as well as learning the disconnected pins require a 'no connection' flag to not throw an error.
    Error correction also prompted the AC power connector symbol change to a plug to attempt to fix an error regarding 'driving' the circuit....more work to be done on error analysis.
    [+-15V_PWR_SUPPLY.sch, 5V_supply.sch, AC_input.sch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]
2020-01-21 Error correction, PWR_FLAG
    PWR_FLAG works like this:
    https://forum.kicad.info/t/errtype-3-pin-connected-to-some-others-pins-but-no-pin-to-drive-it/10946
    Added this in power supplies to get rid of warnings that came up during ERC.
    [+-15V_PWR_SUPPLY.sch, 5V_supply.sch, AC_input.sch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]
2020-01-21 Power Supply Conn Update
    Added screw terminals to AC schematic, fixed pin conn numbers on PSU sheets
    [+-15V_PWR_SUPPLY.sch, 5V_supply.sch, AC_input.sch]
2020-01-24 Refdes update, U20 mod
    I believe that the component symbol for MCP4902 has been incorrectly constructed int he standard Kicad libraries. Pin 9 (~SHDN) is an output per the standard library, however I am fairly certain it is supposed to be an input. I modified the schematic symbol to match what I think is correct.
    [+-15V_PWR_SUPPLY.sch, 5V_supply.sch, AC_input.sch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]
2020-01-24 AC PCB Update
    Removed Switch symbol from PCB, moved to main sheet. Started playing with footprint assignment. Other minor updates.
    [+-15V_PWR_SUPPLY.sch, 5V_supply.sch, AC_input.sch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]
2020-01-24 Initial Footprint Assignment
    Assigned footprints to SMT resistors, pin headers, screw terminals, LEDs, DIP-8 ICs
    [+-15V_PWR_SUPPLY.sch, 5V_supply.sch, AC_input.sch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]
2020-01-27 BOM update
    Minor changes to schematic, value changes and footprint entry. BOM updated with parts sourcing
    [+-15V_PWR_SUPPLY.sch, 5V_supply.sch, AC_input.sch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]
2020-02-02 power headers updated, slight BOM update
    changed footprint on all 5V, +-15V to JST B2B / B3B connectors. All male conns now.
    [+-15V_PWR_SUPPLY.sch, 5V_supply.sch, AC_input.sch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]
2020-02-02 Transformer specification
    updated schematic, BOM with power transformer info. Other minor schematic tweaks.
    [+-15V_PWR_SUPPLY.sch, 5V_supply.sch, AC_input.sch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]
2020-02-02 screw terminal update
    AC power conn update to implement ground. Moved BOM to html file format for web view, not sure if I like it like this but wanted to try it.
    [+-15V_PWR_SUPPLY.sch, 5V_supply.sch, AC_input.sch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]
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2020-02-02 Added front panel LED sheet. BOM update. Front panel PCA work
    other minor changes like LED color assignments, etc
    [+-15V_PWR_SUPPLY.sch, 5V_supply.sch, AC_input.sch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]
2020-02-05 LED resistor update
    In the process of reviewing layouts and associated parts sourcing, I realized that I had incorrectly calculated the resistors needed for the power supply LEDs on all boards. Updated BOM and schematic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
    [+-15V_PWR_SUPPLY.sch, 5V_supply.sch, IO_BALANCED_DAUGHTER.sch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]
2020-02-05 Initial Review
    Reviewing schematic, comparing to references and filling in BOM to match schematics. Updating footprints in the process as well.
    [+-15V_PWR_SUPPLY.sch, IO_BALANCED_DAUGHTER.sch, gain_stage.sch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]
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2020-02-26 Headphone Amp Crossfeed Implementation - using the CMOY modified Linkwitz High Z crossfeed design as a basis.
    [+-15V_PWR_SUPPLY.sch, 5V_supply.sch, AC_input.sch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]
2020-02-27 BOM Update
    Realized that after saving as an HTML document, the file I was manipulating in OpenOffice would be lost once closed. I updated the .odf doc to match what was in the html file, then overwrote the html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
    [preamp BOM.ods]
2020-03-01 Incorporated Standby Relay
    The Relay shown on the AC Input page is meant to control the +/-15V supply. The coil is controlled by two pins on the esp32 MCU. The 5V supply will be active at all times. I think the working conditi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
    [+-15V_PWR_SUPPLY.sch, 5V_supply.sch, AC_input.sch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]
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2020-03-03 Schematic Redesignation
    Regenerated RefDes for all parts, updated BOM accordingly and perfomred check on values, RefDes present from schematic to BOM. Value changes, BOM filled in as a result.
    [+-15V_PWR_SUPPLY.sch, 5V_supply.sch, IO.sch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]
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
